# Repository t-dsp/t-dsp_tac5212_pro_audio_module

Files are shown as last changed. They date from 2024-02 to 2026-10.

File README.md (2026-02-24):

# T-DSP TAC5212 Pro Audio Module

**Part of the [T-DSP](https://t-dsp.com) open modular audio platform.**

A compact (50mm x 34.5mm) stereo audio codec module built around the **Texas Instruments TAC5212** high-performance audio codec.

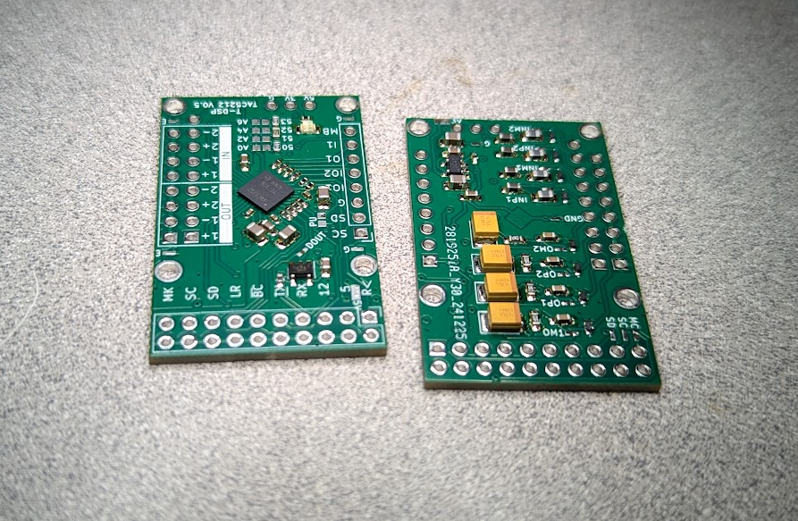
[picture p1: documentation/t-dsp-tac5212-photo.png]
T-DSP TAC5212 Pro Audio Module


T-DSP TAC5212 Pro Audio Module - Top Isometric

| | |
|:---:|:---:|
| Top | Bottom |
| Front | Rear |

**[View 3D Render Gallery](https://t-dsp.github.io/t-dsp_tac5212_pro_audio_module/gallery.html)** -- interactive slideshow of all board views

## About T-DSP

T-DSP is an open modular audio platform designed for musicians, engineers, and developers who want powerful digital signal processing in a flexible, hackable format. Built around the [Teensy](https://www.pjrc.com/teensy/) microcontroller and the [Teensy Audio Library](https://www.pjrc.com/teensy/td_libs_Audio.html), T-DSP combines studio-quality audio with a growing library of open-source modules for mixing, synthesis, effects, and more.

Whether you're building a custom digital mixer, crafting a unique instrument, or prototyping audio products, T-DSP gives you the tools to bring your ideas to life.

Join the community, contribute to the library, or grab a module and start patching. Learn more at [t-dsp.com](https://t-dsp.com).

## Overview

This codec module provides stereo ADC and DAC conversion and is one of the core building blocks of the T-DSP platform. It is designed as a **chip-on-board module** -- a complete, self-contained audio codec that solders directly onto a user-designed backplane PCB, just like any other component. A KiCad footprint is provided so you can drop the module into your own backplane design, add whatever jacks and connectors your application needs, and build a custom audio device without dealing with codec layout or analog design.

## Audio Capabilities

### Inputs (2 differential pairs)
- Line-level (consumer -10dBV or professional +4dBu)
- Instrument-level (guitar/bass) with external preamp/buffer (preamp and buffer modules are on the T-DSP project roadmap)
- Microphone (dynamic, with up to 12dB analog channel gain and additional digital gain)
- Programmable input impedance (5k/10k/40k ohm), DC-coupled. Optional 100k ohm bias resistors on board.
- 2 VRMS full-scale differential input

### Outputs (2 differential pairs)
- Headphone drive (16-300 ohm, 62.5mW @ 16 ohm, ~31mW @ 32 ohm)
- Consumer line out (-10dBV)
- Professional balanced output (+4dBu)
- 10 ohm output impedance, 2 VRMS differential output

## Digital Interface

- **I2S/PCM** audio data (DIN, DOUT, BCLK, LRCK, MCLK)
- **I2C** control bus for codec register configuration
- **GPIO** pins for additional control and sensing

The T-DSP platform is developed with [Teensy](https://www.pjrc.com/teensy/) and the [Teensy Audio Library](https://www.pjrc.com/teensy/td_libs_Audio.html), but the module uses standard I2S and I2C interfaces and can work with any compatible microcontroller or DSP platform.

## Modular Architecture

The module connects to your backplane via **2.54mm (0.1") header pins** (52 pins total), organized into functional groups. Headers can be male/female for a removable connection, or soldered permanently with straight pins:

- **DSP IO** (20 pins) -- digital audio (I2S), I2C control, MCLK, and power. Also available as a 20-pin ribbon header for off-board connection via standard ribbon cable.
- **Analog IO** (16 pins) -- stereo input and output pairs with analog ground references.
- **GPIO** (8 pins) -- additional I2C, general-purpose IO, and digital ground.
- **Power** (8 pins) -- 5V, 3.3V, MIC_BIAS, and ground lines.

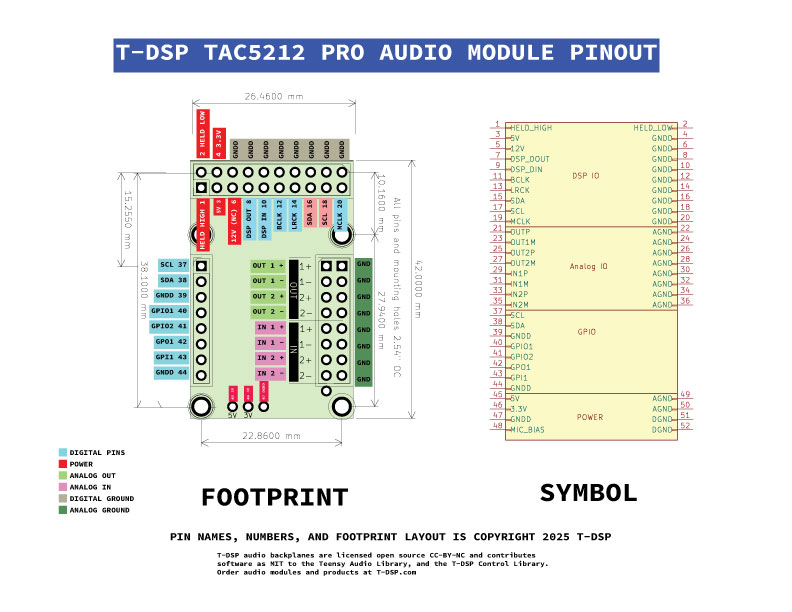
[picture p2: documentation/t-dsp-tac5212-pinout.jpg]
T-DSP TAC5212 Pro Audio Module Pinout


### Backplane Integration

A KiCad footprint for the module is included in `/lib_fp/`, allowing you to import it directly into your own backplane PCB design. You handle the jacks, connectors, and mechanical layout on your backplane -- the module takes care of codec, filtering, and power regulation.

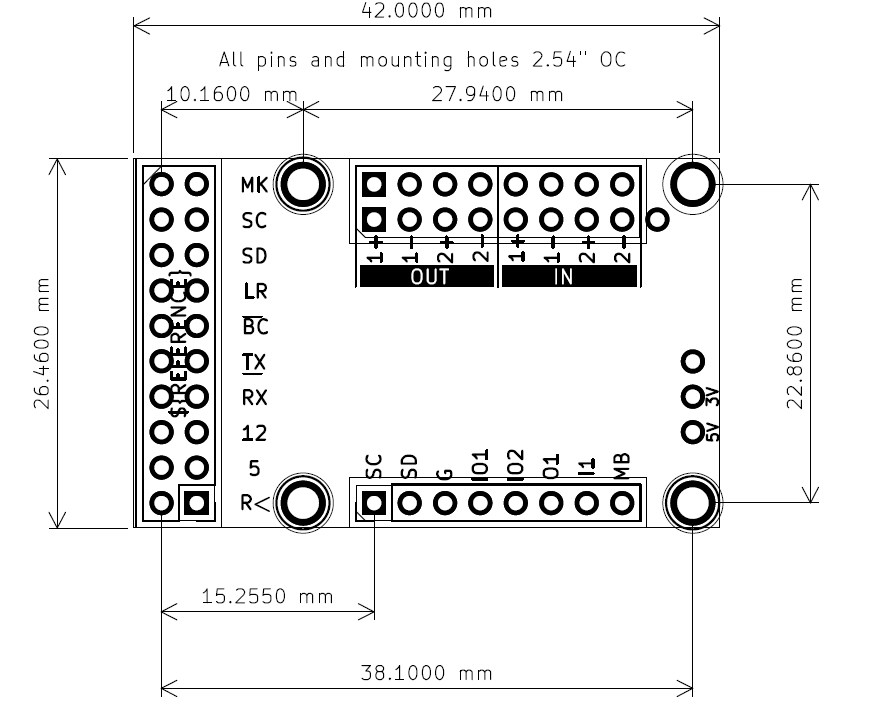
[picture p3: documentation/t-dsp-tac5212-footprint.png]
T-DSP TAC5212 Pro Audio Module Footprint


**Example backplanes built with the T-DSP module:**

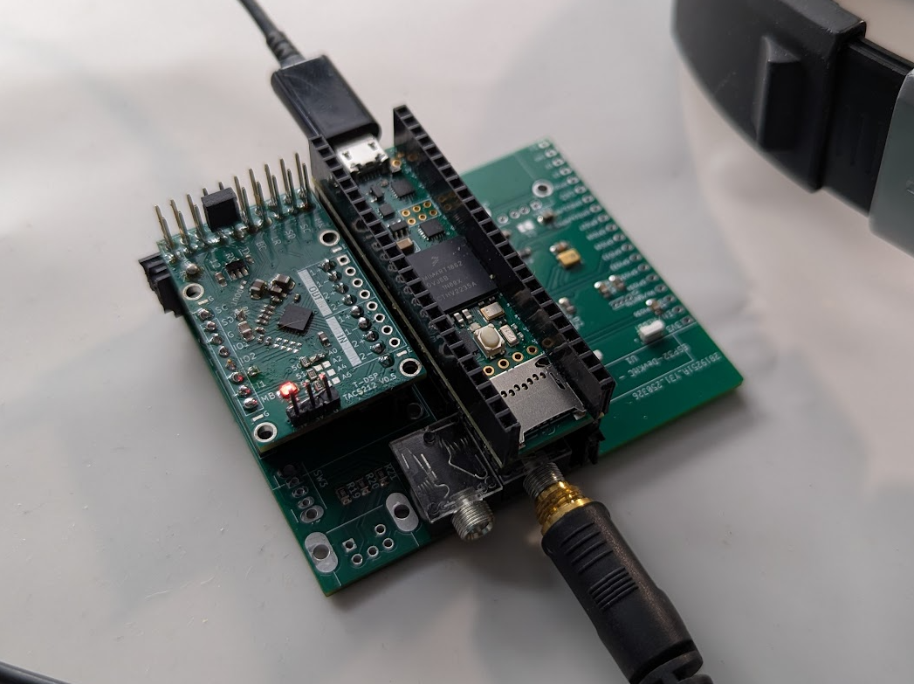
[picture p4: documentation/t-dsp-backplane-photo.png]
Backplane example - prototype


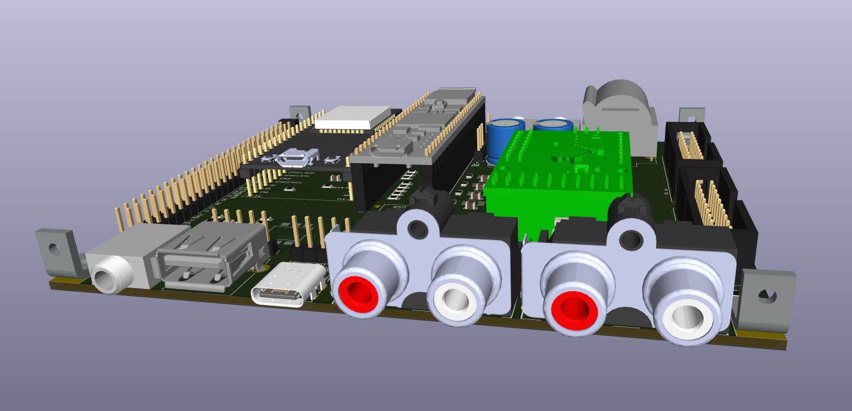
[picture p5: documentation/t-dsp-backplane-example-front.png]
Backplane example - 3D front

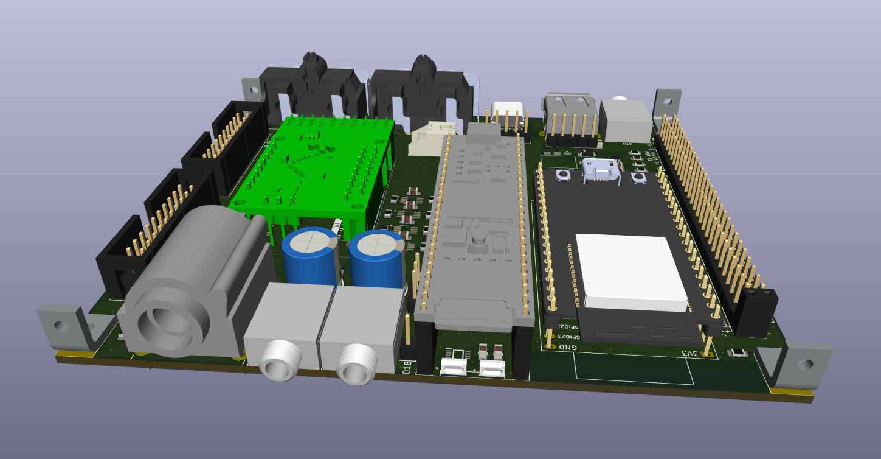
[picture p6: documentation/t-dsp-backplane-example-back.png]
Backplane example - 3D back


### Multi-Module Chaining

Because the digital outputs are buffered on each module, multiple modules can run together on the same digital bus. You can daisy-chain modules in two ways:

- **On the backplane** -- route the digital bus as board traces between multiple module footprints.
- **Via ribbon cable** -- use a ribbon cable with multiple taps to connect up to 4 modules per chain.

System designers only need to focus on analog signal routing. The buffered digital bus works reliably over longer distances and across many modules.

## On-Board Circuitry

- LDO regulator for clean 3.3V analog power
- Buffered digital outputs for reliable backplane distribution
- TVS protection on audio outputs
- Ferrite bead RF filtering on audio inputs
- Solder jumpers for I2C address configuration
- Power indicator LED

The T-DSP platform has gone through several design iterations. The bench prototype below is from an earlier version of the project -- a different module architecture that helped shape the current design.

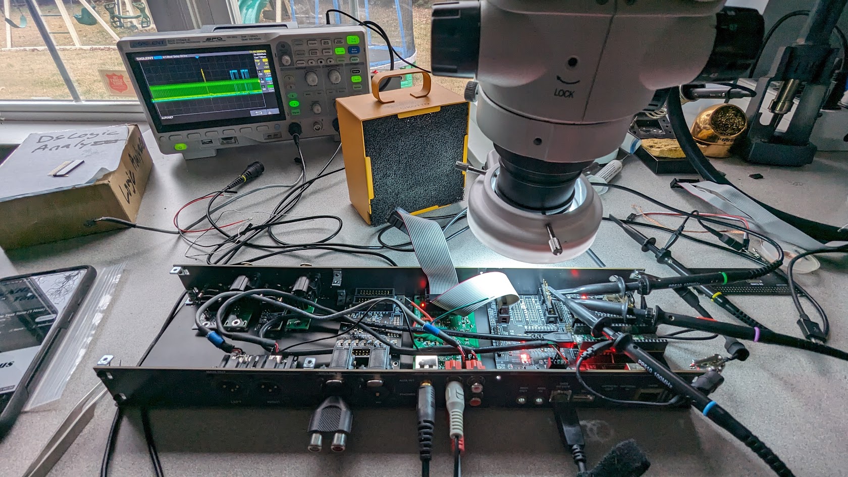
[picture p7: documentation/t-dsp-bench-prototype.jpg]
Earlier T-DSP prototype on the bench


## Project Files

| Directory | Contents |
|---|---|
| `/3d_models/` | 3D models for PCB components and enclosure |
| `/documentation/` | TAC5212 datasheets, [schematic PDF](documentation/t-dsp-tac5212-schematic.pdf), [footprint drawing](documentation/t-dsp-tac5212-footprint.pdf), and [3D model (STL)](documentation/t-dsp_tac5212_pro_audio_module.stl). View online: [schematic](https://kicanvas.org/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) and [PCB layout](https://kicanvas.org/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) via KiCanvas |
| `/lib_fp/` | Custom KiCad footprint libraries |
| `/lib_sch/` | Custom KiCad schematic symbol libraries |
| `/pages/` | [3D Render Gallery](https://t-dsp.github.io/t-dsp_tac5212_pro_audio_module/gallery.html), [Interactive BOM](https://t-dsp.github.io/t-dsp_tac5212_pro_audio_module/ibom.html) |
| `/scripts/` | LCSC enrichment and BOM verification scripts |

## Building Manufacturing Files

Manufacturing files (gerbers, drill, BOMs, CPL, interactive BOM) are generated automatically by [KiBot](https://github.com/INTI-CMNB/KiBot) via GitHub Actions on every push to `main`. Download the ZIP from the **Actions** tab or from **Releases**.

The ZIP includes:
- Gerbers and drill files for any PCB fabricator
- JLCPCB BOM (`*_bom_JLCPCB.csv`) with LCSC part numbers
- Generic BOM (`*_bom_generic.csv`) with manufacturer part numbers
- Pick and place / CPL file
- Schematic PDF and PCB layout PDF
- Interactive BOM (also deployed live: [view iBOM](https://t-dsp.github.io/t-dsp_tac5212_pro_audio_module/ibom.html))

To build locally, install [Docker](https://www.docker.com/) and run:

```powershell
docker run --rm -v "${PWD}:/workspace" -w /workspace ghcr.io/inti-cmnb/kicad9_auto:latest kibot -c .kibot.yaml -b t-dsp_tac5212_pro_audio_module.kicad_pcb -e t-dsp_tac5212_pro_audio_module.kicad_sch -d manufacturing
```

Output files appear in `manufacturing/t-dsp_tac5212_pro_audio_module/`.

## Related Projects

Browse all T-DSP modules and backplanes on the [T-DSP GitHub organization](https://github.com/orgs/t-dsp/repositories).

## Status

This revision has not yet been built. The previous board was functional but had a few signal routing errors and needed a redesign of the analog output stage for low-impedance headphone drive. Those issues have been addressed in the current design.

If you build one, we'd love to hear how it goes -- please open an issue or reach out with your findings.

## Contact

For consulting, custom backplane design, or commercial licensing inquiries, reach out via [LinkedIn](https://linkedin.com/in/jayshoe).

## License

This project is licensed under the [Creative Commons Attribution-NonCommercial-ShareAlike 4.0 International (CC BY-NC-SA 4.0)](https://creativecommons.org/licenses/by-nc-sa/4.0/).

You are free to share and adapt this work for non-commercial purposes, as long as you give appropriate credit and distribute any derivatives under the same license.

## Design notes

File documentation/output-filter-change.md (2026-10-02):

# DAC output filter change (next respin / rework of built units)

**Date:** 2026-10-02
**Status:** Decided, not yet applied to the schematic. BOM change only, no layout change.

## Symptom

Harsh, fatiguing top end from the DAC outputs. Present on headphones, much worse through a
power amplifier and speakers. The module is wired straight to the amplifier; the backplanes
(`t-dsp_XLR_2x2`, `t-dsp_RCA_8x8`) only add a coupling capacitor before the jack, so nothing
between the codec and the amplifier filters the DAC's out-of-band noise.

## Cause

The output network on every DAC leg is 10 R in series and 4.7 nF to AGND. Its corner is about
3.4 MHz, so the delta-sigma noise from a few hundred kHz upward reaches the cable and the
amplifier input unattenuated. Some amplifier input stages fold that back into the audio band.

## Current network (identical on all four legs)

| Position | OUT1P / OUT1M / OUT2P / OUT2M | Value | Fitted |
|---|---|---|---|
| Series | R108 / R111 / R132 / R135 | 10 R, 0603 | yes |
| Parallel to series R | R127 / R128 / R129 / R130 | 0603, "DNP" | no |
| Shunt to AGND | C113 / C114 / C120 / C122 | 4.7 nF, 0603 | yes |
| Coupling link | R161 / R162 / R163 / R134 | 0 R, 0603 | yes |
| Coupling cap (alternative to the link) | C110 / C117 / C121 / C123 | 47 uF, EIA-3528 | no |
| ESD at the connector | D108 / D109 / D110 / D111 | TPD1E10B06, 0402 | yes |

Connector: board_outline108 pins 21 (OUT1P+), 23 (OUT1M+), 25 (OUT2P+), 27 (OUT2M+), AGND on
22 / 24 / 26 / 28. "Earth" is the analog ground net.

## The change

| References | Now | Change to | Part | LCSC |
|---|---|---|---|---|
| R108, R111, R132, R135 | 10 R | **220 R** 1 %, 0603 | Uniroyal 0603WAF2200T5E | C22962 (Basic) |
| C113, C114, C120, C122 | 4.7 nF | **10 nF C0G 50 V**, 0603 | Murata GRM1885C1H103JA01D | C85973 |

Everything else stays as it is: 0 R links fitted, 47 uF caps not fitted, R127-R130 not fitted,
ESD diodes unchanged.

Result: first-order corner at 72 kHz. -0.3 dB at 20 kHz, -9 dB at 200 kHz, -23 dB at 1 MHz,
-32 dB at 3 MHz. 220 R into a 47 k amplifier input loses 0.04 dB; into 10 k, 0.19 dB.

Why 220 R / 10 nF rather than 100 R / 22 nF: same corner, and the 10 nF C0G is a stocked
Murata part with a verified LCSC listing. Use C0G/NP0 (not X7R) and matched parts: X7R adds
voltage-dependent distortion, and a P/M mismatch converts common-mode noise to signal on a
balanced input.

## Before ordering: bench test on a current unit

1. Solder a 100 nF film cap across an RCA jack (tip to sleeve) on the RCA backplane, or 47 nF
   across XLR pins 2 and 3 on the XLR backplane. With the module's 10 R this makes a corner near
   160 kHz.
2. If the harshness disappears, the BOM change above is the production fix.
3. Remove the test cap once the module is changed. A large cap at the jack together with the
   220 R would start eating the top octave (100 nF with 220 R is a 7 kHz corner).

## Backplane notes (no change required for this fix)

- XLR 2x2: 470 uF electrolytic per leg to XLR pins 2 and 3. Polar: positive end toward the
  module (the codec pin sits at about 1.5 V DC). Not phantom-safe: 48 V phantom on a mixer input
  charges those caps the wrong way and reaches the module. Add 100 R per leg and a clamp before
  that board goes to anyone else.
- RCA 8x8: Nichicon UEP 10 uF bipolar on the P leg, M leg open. Fine as is.
- Optional second pole at the jack on a future backplane spin: 100 R in series and 2.2 nF to
  AGND right at the jack (XLR: 2.2 nF across pins 2 and 3 plus 1 nF from each leg to pin 1).
  Only needed if a trace of edge remains after the module change.

## Single-ended and balanced use

The same build serves both. Balanced: take P and M. Single-ended: take P and AGND, leave M
open. If a build is to be DC-blocked on the module instead of on the backplane, fit the 47 uF
on the EIA-3528 pads (B-case polymer tantalum, 47 uF 6.3 V, positive end toward the codec) and
remove the corresponding 0 R link.

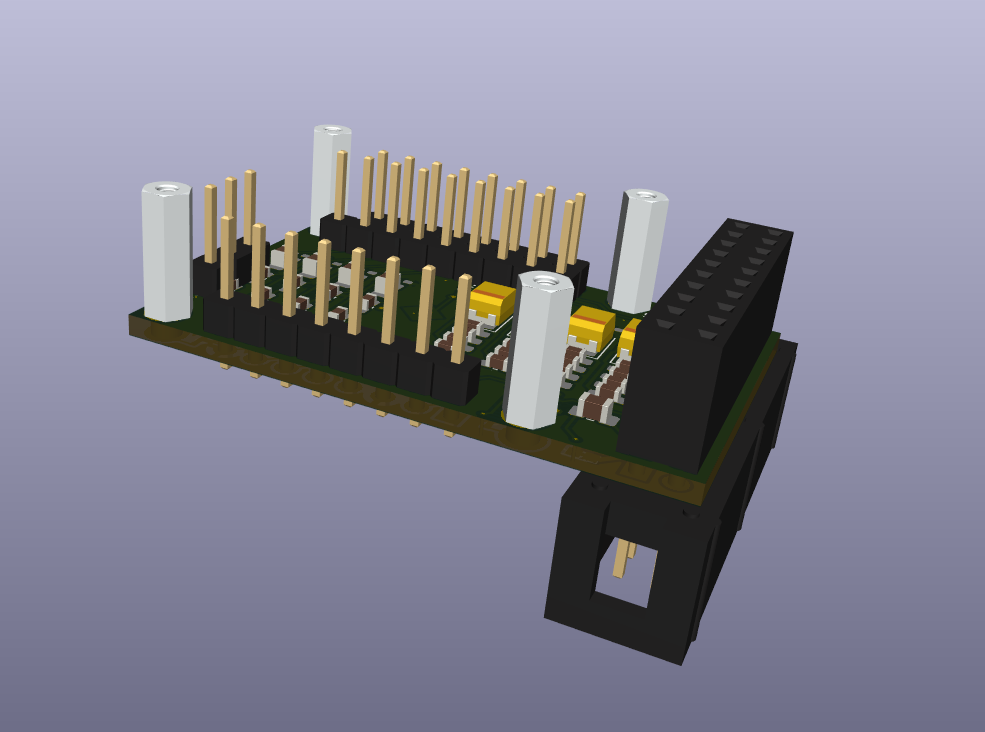
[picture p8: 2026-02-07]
documentation/t-dsp-tac5212-3d-bottom.png

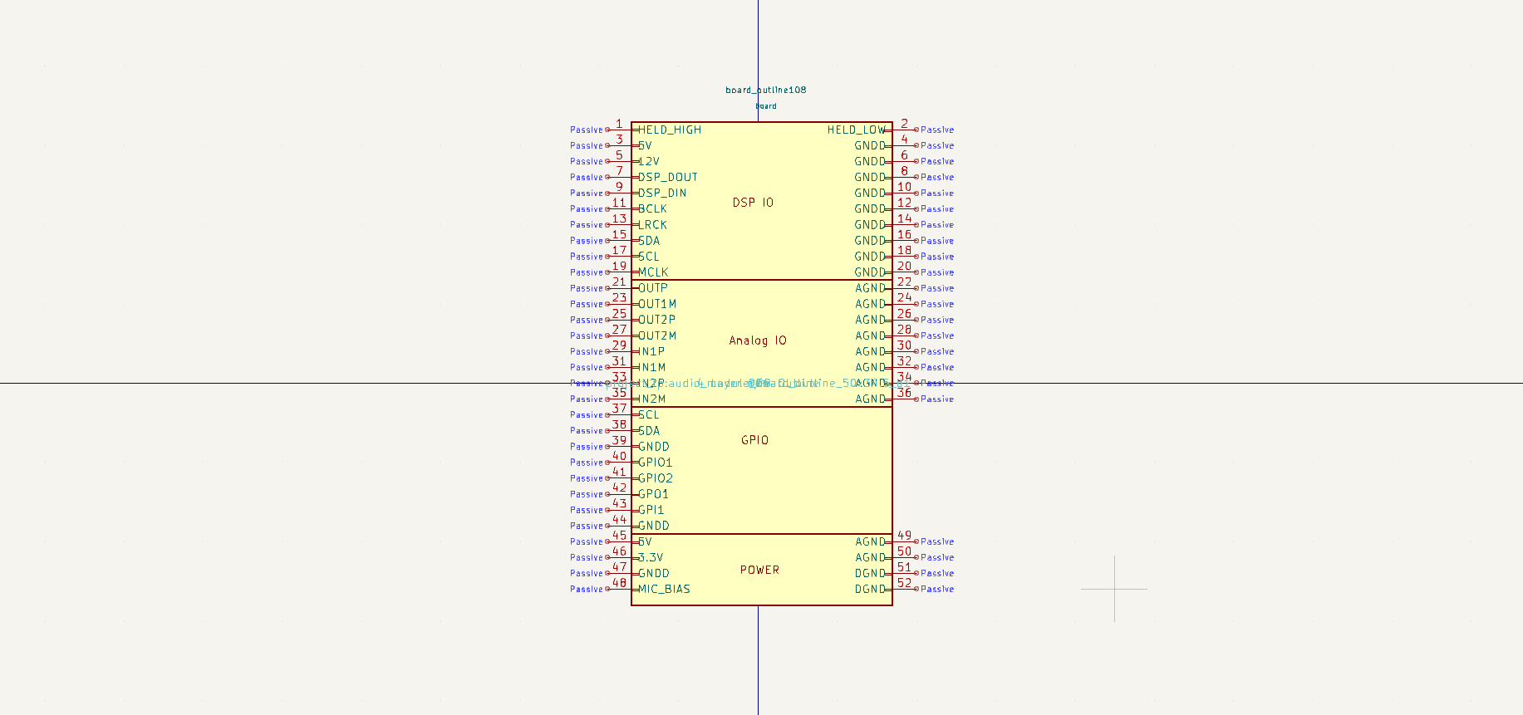
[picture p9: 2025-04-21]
documentation/t-dsp-tac5212-symbol.png

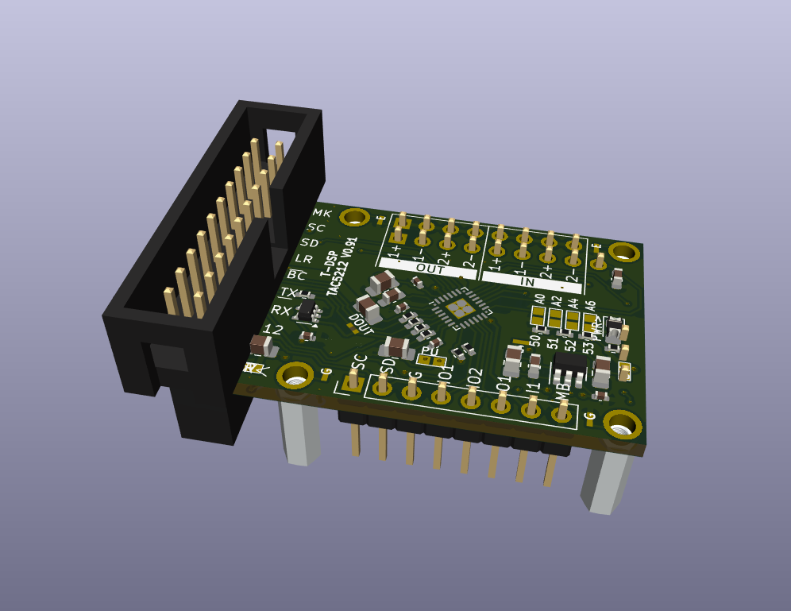
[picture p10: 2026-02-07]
documentation/t-dsp-tac5212-3d-top.png

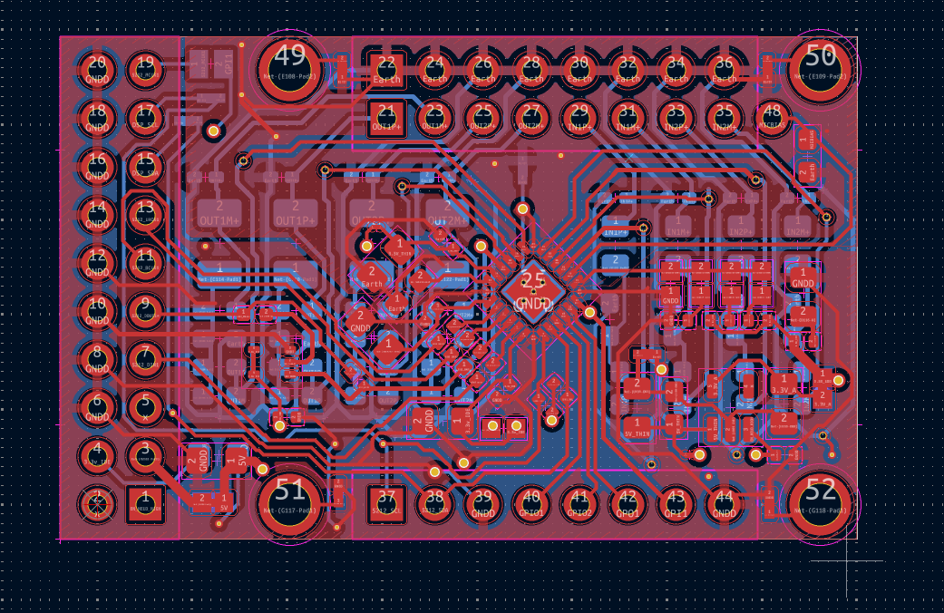
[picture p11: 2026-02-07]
documentation/t-dsp-tac5212-pcb-layout.png

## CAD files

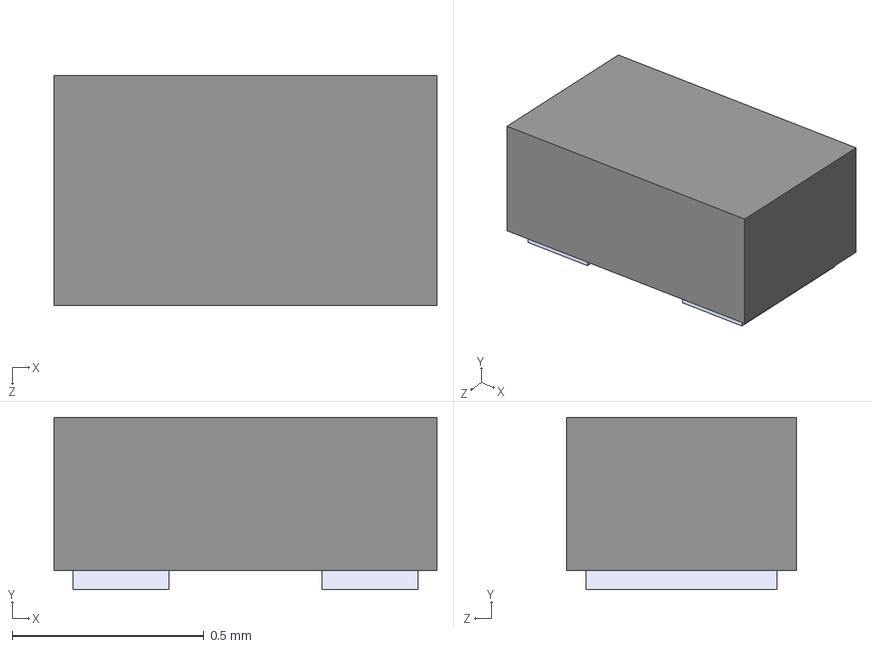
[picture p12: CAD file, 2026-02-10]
3d_models/TPD1E10B06DPYR.STEP
1.00 x 0.45 x 0.6 mm

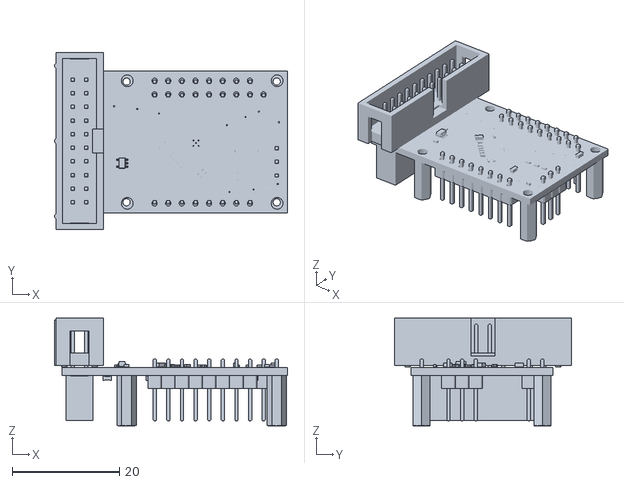
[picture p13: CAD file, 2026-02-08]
documentation/t-dsp_tac5212_pro_audio_module.stl
43.4 x 33.1 x 20.0

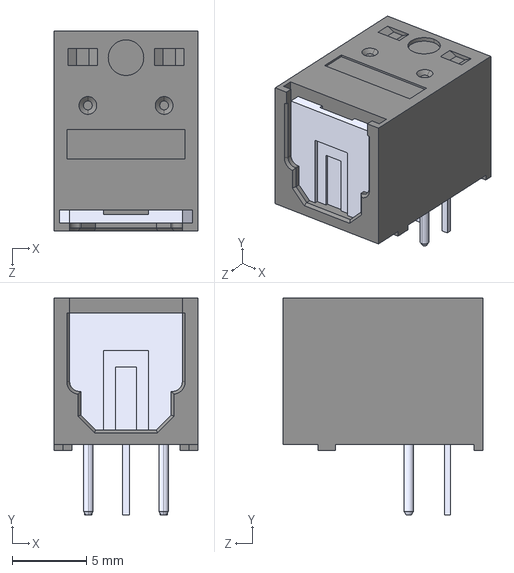
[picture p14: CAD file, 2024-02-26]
lib_sch/PLT133_T10W/PLT133_T10W.step
9.70 x 14.7 x 13.5 mm

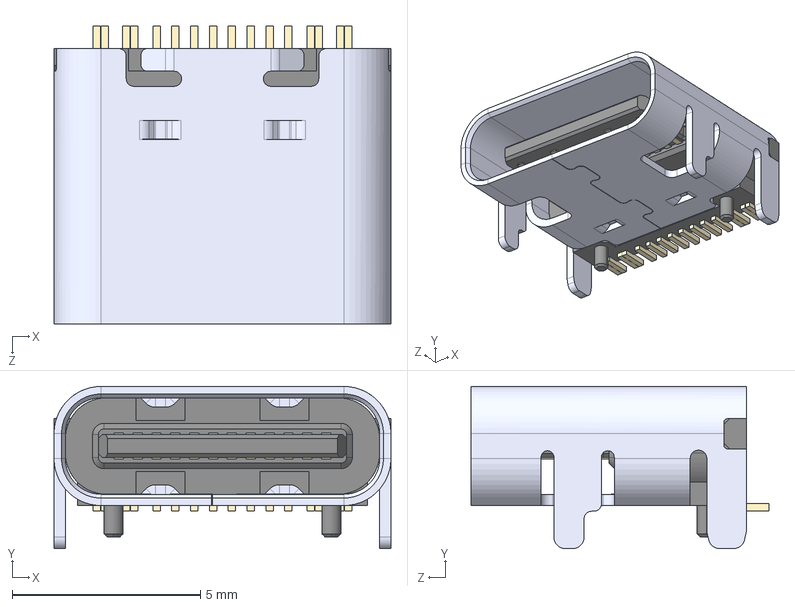
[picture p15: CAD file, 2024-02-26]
lib_sch/TYPE-C-31-M-12/TYPE-C-31-M-12.step
8.94 x 4.30 x 7.90 mm

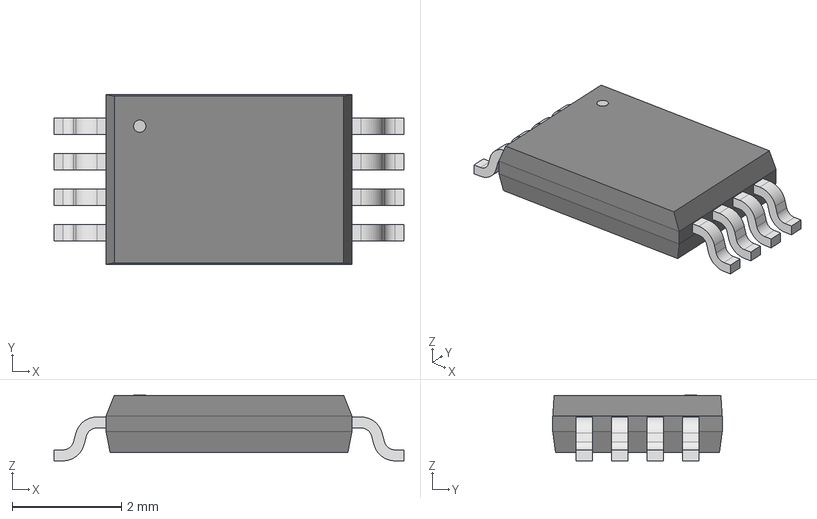
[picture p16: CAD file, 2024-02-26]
lib_sch/ul_23LC1024IST/2020-04-10_17-26-26/STEP/TSSOP8_MC.step
6.40 x 3.10 x 1.20 mm

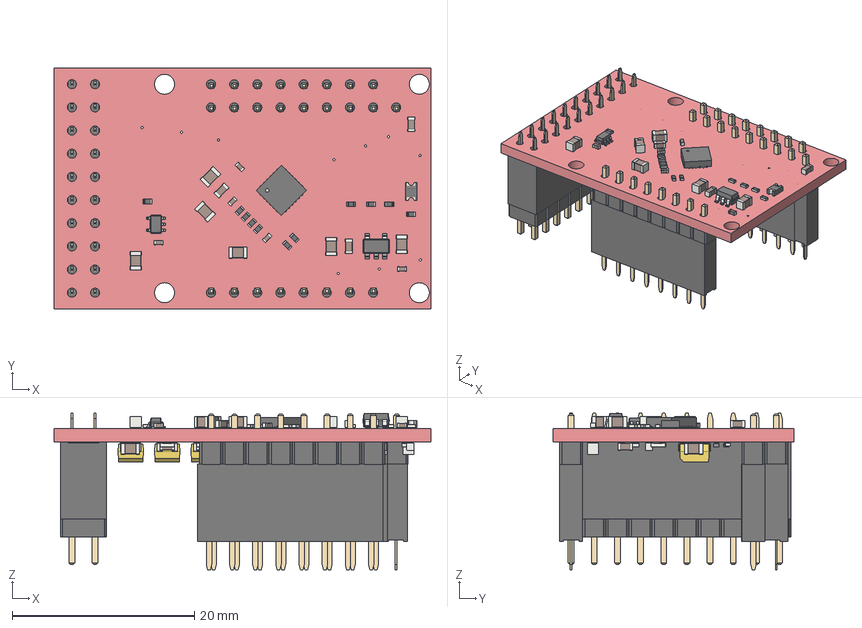
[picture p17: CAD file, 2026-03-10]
t-dsp_tac5212_pro_audio_module_pcb_mount.step
41.3 x 26.5 x 17.2 mm
R_0402_1005Metric x 15
PinHeader_1x08_P2.54mm_Vertical x 2
PinHeader_1x09_P2.54mm_Vertical
PinSocket_2x10_P2.54mm_Vertical
PinSocket_2x08_P2.54mm_Vertical
PinSocket_1x08_P2.54mm_Vertical
PinSocket_1x01_P2.54mm_Vertical
PinHeader_2x10_P2.54mm_Vertical
C_0805_2012Metric x 11
C_0402_1005Metric x 5
C_0603_1608Metric x 11
SOT-353_SC-70-5
SOT-23-5
D_0805_2012Metric
VQFN-24-1EP_4x4mm_P0.5mm_EP2.45x2.45mm
R_0603_1608Metric x 16
CP_EIA-3528-21_Kemet-B x 4
TPD1E10B06DPYR x 8
t-dsp_tac5212_pro_audio_module_PCB

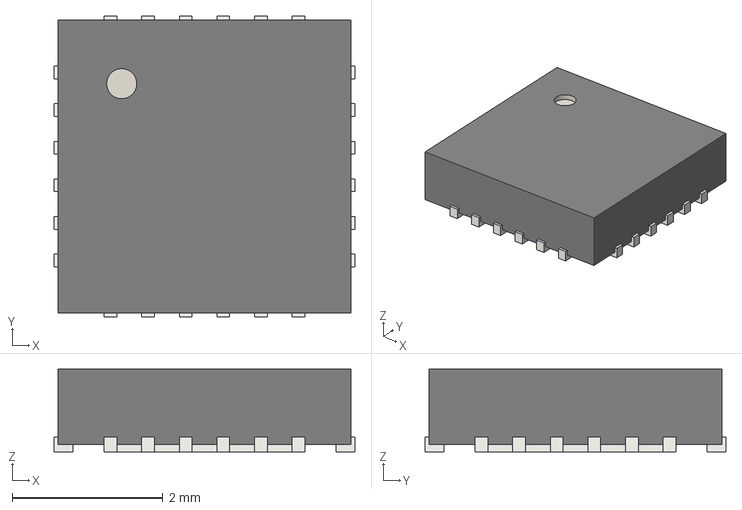
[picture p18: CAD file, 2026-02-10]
3d_models/VQFN-24-1EP_4x4mm_P0.5mm_EP2.45x2.45mm.step
4.00 x 4.00 x 1.10 mm

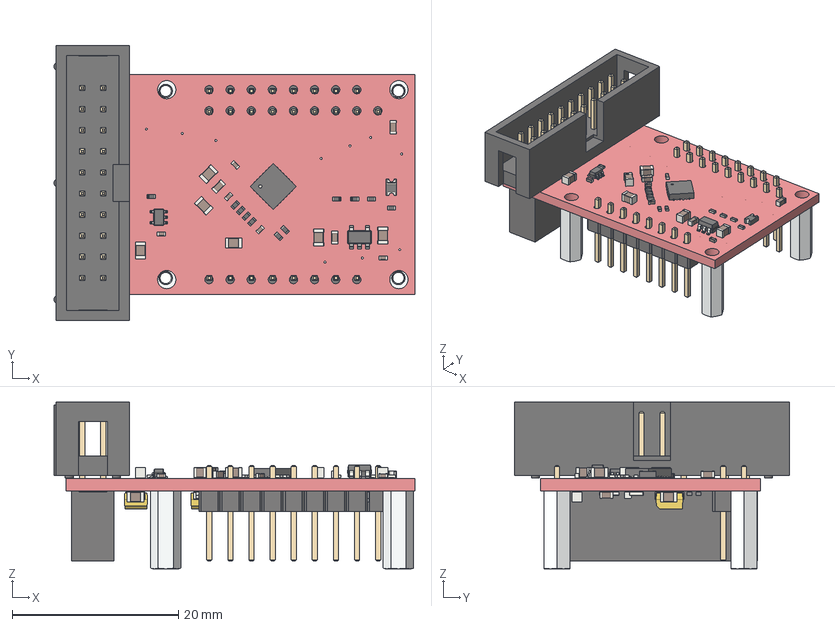
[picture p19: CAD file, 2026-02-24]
t-dsp_tac5212_pro_audio_module.step
43.4 x 33.1 x 20.0 mm
R_0402_1005Metric x 11
IDC-Header_2x10_P2.54mm_Vertical
1808--3DModel-STEP-630548 x 4
PinHeader_1x08_P2.54mm_Vertical x 2
PinHeader_1x09_P2.54mm_Vertical
PinSocket_2x10_P2.54mm_Vertical
C_0805_2012Metric x 11
C_0402_1005Metric x 5
C_0603_1608Metric x 11
SOT-353_SC-70-5
SOT-23-5
D_0805_2012Metric
VQFN-24-1EP_4x4mm_P0.5mm_EP2.45x2.45mm
R_0603_1608Metric x 16
CP_EIA-3528-21_Kemet-B x 4
TPD1E10B06DPYR x 8
t-dsp_tac5212_pro_audio_module_PCB

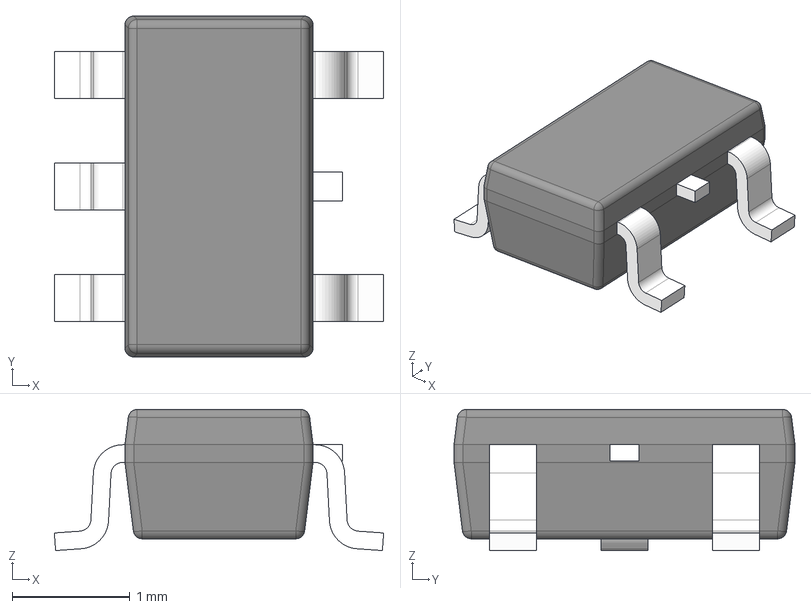
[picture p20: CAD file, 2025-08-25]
3d_models/SN74LVC1G66DBVR.stp
2.80 x 2.90 x 1.20 mm
BODY-SOT
LEAD-SOT x 5
LEAD-DUMMY

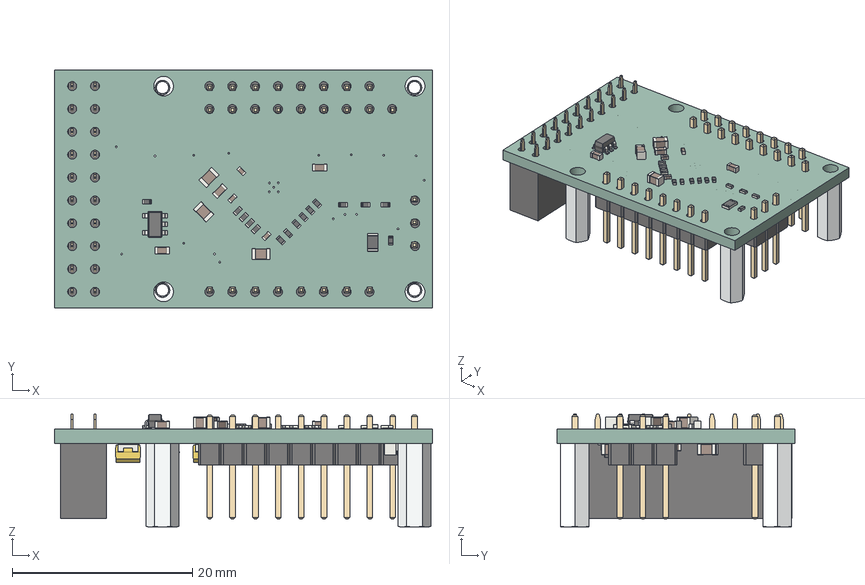
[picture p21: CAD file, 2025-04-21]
tlv320aic3105_audio_board50.step
42.0 x 26.5 x 12.5 mm
R_0402_1005Metric x 16
PinHeader_1x08_P254mm_Vertical x 2
PinHeader_1x09_P254mm_Vertical
PinSocket_2x10_P2.54mm_Vertical
PinHeader_1x03_P254mm_Vertical
C_0805_2012Metric x 9
C_0402_1005Metric x 3
SOT_23_5 x 2
C_0603_1608Metric x 13
R_0805_2012Metric
R_0603_1608Metric x 4
CP_EIA_3528_21_Kemet_B x 4
_autosave-tac5212_audio_board_single_ended_PCB

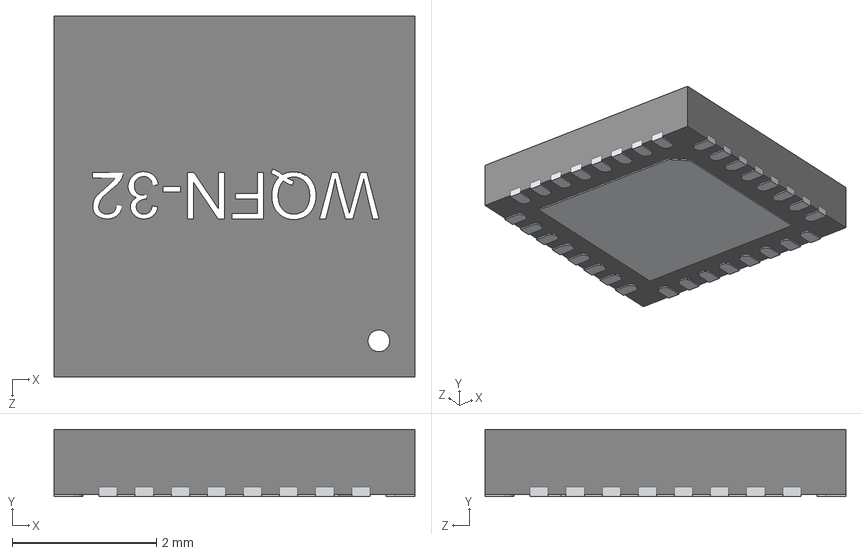
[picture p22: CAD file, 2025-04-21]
3d_models/WQFN-32.step
5.00 x 0.93 x 5.00 mm

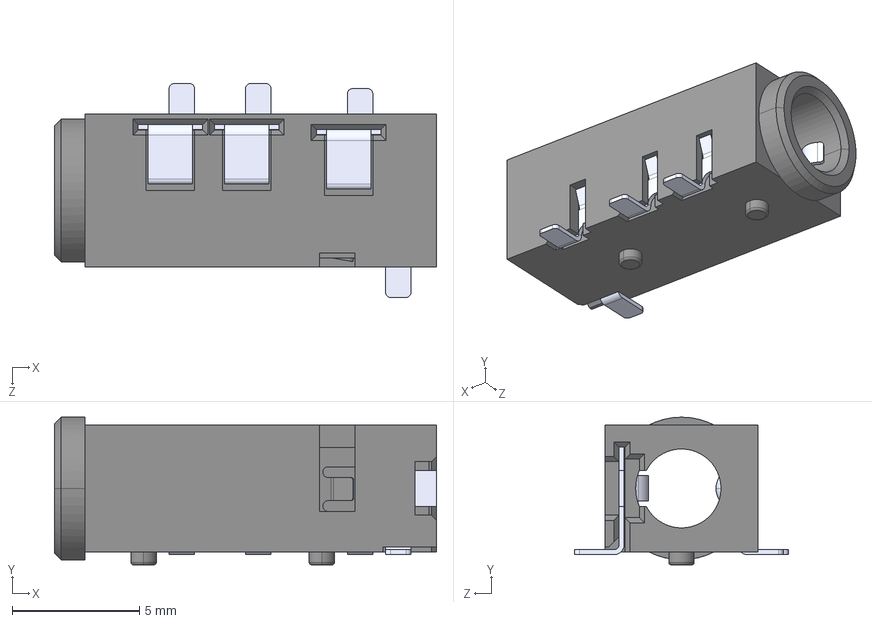
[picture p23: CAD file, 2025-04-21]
3d_models/SJ2-3574A-SMT-TR.step
15.0 x 5.80 x 8.40 mm

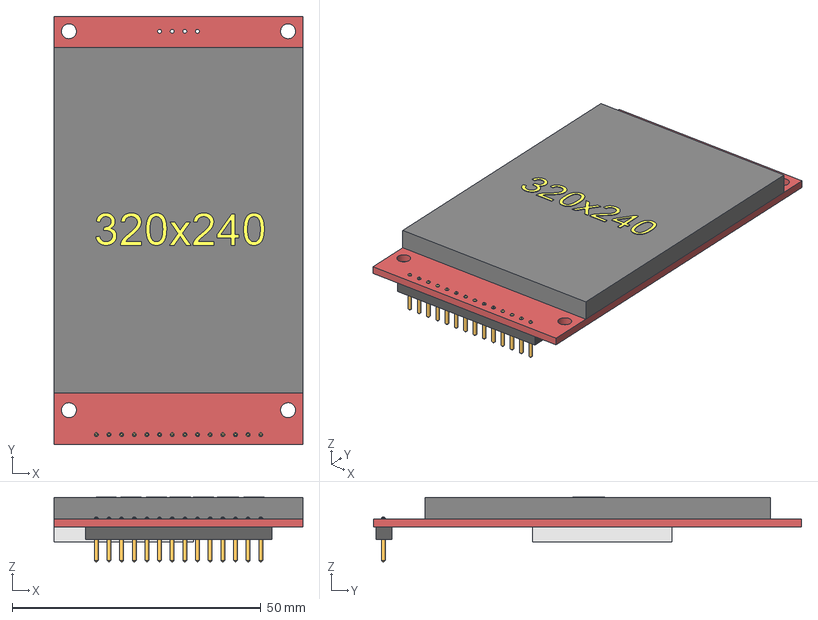
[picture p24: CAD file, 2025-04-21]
3d_models/TFT_320x240_touch_r0.step
50.0 x 86.0 x 13.1 mm
Body-header
Body-pins
Body-display
Body-sdcard
Body-board

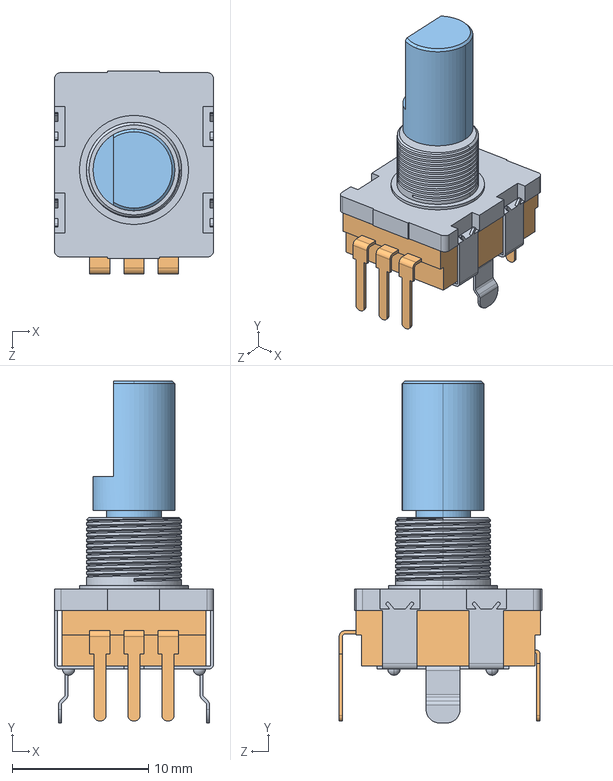
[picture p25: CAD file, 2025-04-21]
3d_models/EN11-HSM1AF15.STEP
11.7 x 25.1 x 14.9 mm

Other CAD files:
lib_sch/ul_23LC1024IST/2020-04-10_17-26-26/STEP/TSSOP8_MC-M.step
lib_sch/ul_23LC1024IST/2020-04-10_17-26-26/STEP/TSSOP8_MC-L.step
3d_models/SK6812.step
3d_models/1808--3DModel-STEP-630548.STEP
3d_models/2120--3DModel-STEP-630548.STEP
3d_models/3-D NC3MAH.stp
3d_models/3-D NCJ6FAH.stp
3d_models/3-D NCJ6FI-H-0.stp
3d_models/3-d-nmj6hcd3.stp
3d_models/3.5MM_STEREO_35RAPC4BHN2.STEP
3d_models/35RAPC3BH3.STEP
3d_models/35RAPC7JS.STEP
3d_models/35RAPC7JS_SIMPLIFIED.step
3d_models/3_2SPI-TFT-Modul_ILI9341.STEP
3d_models/4691.step
3d_models/74LS00.step
3d_models/Bracket 4-40 621.STEP
3d_models/COMBO-NCJ6FA-H.step
3d_models/COMBO_XLR_NCJ6FI-H-0.stp
3d_models/DC_BARREL_PJ-202AH.step
3d_models/DIN-5.STEP
3d_models/FCR6842032R ORJ3.stp
3d_models/FCR6842032T OTJ3.stp
3d_models/J1B1211CCD.STEP
3d_models/JST - XH - Thru (V) - 2Pin - 2.54mm.stp
3d_models/LED_SK6812MINI-E.step
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

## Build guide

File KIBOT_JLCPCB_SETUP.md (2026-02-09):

# KiBot JLCPCB Setup Notes

Reference for generating JLCPCB-ready manufacturing files from KiCad using KiBot + Docker.

## Prerequisites

- **Docker**: Required (kicad-cli and KiBot are NOT installed locally)
- **Docker image**: `ghcr.io/inti-cmnb/kicad9_auto:latest` (bundles KiBot + KiCad 9)
- Pull it first: `docker pull ghcr.io/inti-cmnb/kicad9_auto:latest`

## Project Files

```
t-dsp_tac5212_pro_audio_module.kicad_pro
t-dsp_tac5212_pro_audio_module.kicad_pcb   (4-layer: F.Cu, In1.Cu, In2.Cu, B.Cu)
t-dsp_tac5212_pro_audio_module.kicad_sch   (LCSC field with 237 occurrences)
```

## Run Command

PowerShell:
```powershell
docker run --rm -v "${PWD}:/workspace" -w /workspace ghcr.io/inti-cmnb/kicad9_auto:latest kibot -c .kibot.yaml -b t-dsp_tac5212_pro_audio_module.kicad_pcb -e t-dsp_tac5212_pro_audio_module.kicad_sch
```

cmd.exe:
```cmd
docker run --rm -v "%cd%:/workspace" -w /workspace ghcr.io/inti-cmnb/kicad9_auto:latest kibot -c .kibot.yaml -b t-dsp_tac5212_pro_audio_module.kicad_pcb -e t-dsp_tac5212_pro_audio_module.kicad_sch
```

Git Bash (must disable MSYS path conversion):
```bash
MSYS_NO_PATHCONV=1 docker run --rm -v "${PWD}:/workspace" -w /workspace ghcr.io/inti-cmnb/kicad9_auto:latest kibot -c .kibot.yaml -b t-dsp_tac5212_pro_audio_module.kicad_pcb -e t-dsp_tac5212_pro_audio_module.kicad_sch
```

## Output

All files go to `JLCPCB/` directory:
- Gerber files (.gtl, .gbl, .g1, .g2, .gto, .gbo, .gts, .gbs, .gtp, .gbp, .gm1)
- Drill files (-PTH.drl, -NPTH.drl, drill maps)
- BOM CSV: columns = Comment, Designator, Footprint, LCSC Part #
- CPL CSV: columns = Designator, Val, Package, Mid X, Mid Y, Rotation, Layer
- ZIP containing everything above

## Issues to Fix Before Running

### 1. Malformed Reference Designators (BLOCKING)

KiBot will ERROR and skip BOM/CPL generation if any reference designator starts with a digit.

Two components have this problem:
- **`5V108`** — Device:NetTie_2, value "jumper", footprint project_fp:jumper_slice_1mm, DNP, at (57.15, 226.06) in schematic
- **`3V108`** — Device:NetTie_2, value "jumper", footprint project_fp:jumper_slice_1mm, DNP, at (116.84, 355.6) in schematic

**Fix in KiCad**: Rename these to valid designators (e.g. NT110, NT111 or JP110, JP111). KiCad will automatically update the associated net names. Do this in KiCad's schematic editor (not by text editing) so it handles all the cross-references properly.

Note: NT108 and NT109 already exist in the schematic (different net ties with footprint NetTie-2_SMD_Pad0.2mm), so don't use those numbers.

Gerbers generate fine from the PCB file regardless — only BOM/CPL are blocked.

### 2. Non-Blocking Warnings (cosmetic, won't prevent output)

**Trailing spaces in TAC5212EVM fields (W037):**
- D116: `LTST-C170KRKT ` (trailing space)
- R115, R118, R119: `ERJ-2GE0R00X ` (trailing space)
- Fix: Edit these fields in KiCad symbol properties, remove trailing space

**Missing library components (W043):**
- `proejct_lib:Jumper_NO_Small-Device_1` and `_2`
- Note the typo: "proejct" not "project"
- The whole project uses `proejct_lib` throughout — this is a legacy typo baked into the project

**Malformed component values (W020/W127):**
- C113, C114, C120, C122: `0.0047µF (4.7nF)` — KiBot can't parse this format. Consider `4.7nF`
- C124: `10UF confirm polarity` — extra text. Consider `10uF`
- R120: `2.21k ohm` — redundant "ohm". Consider `2.21k`

**BOM field conflicts (W004):**
These happen when KiBot groups components with same Value but different metadata. Not output-breaking but may indicate real BOM issues:
- C109,C112,C116 (0402) grouped with C128,C129 (0603) — same value "0.1uF" but different packages
- C124-C127: package mismatch C0805 vs C0603
- R120,R121,R126: different LCSC codes (C138019 vs C60491) — R126 may be a different value (100K vs 2.21k)

## .kibot.yaml Configuration

Place this file at the repo root as `.kibot.yaml`:

```yaml
# KiBot configuration for JLCPCB manufacturing outputs
# Project: T-DSP TAC5212 Pro Audio Module
# Board: 4-layer (F.Cu, In1.Cu, In2.Cu, B.Cu)

kibot:
  version: 1

filters:
  - name: only_jlc_parts
    comment: 'Only parts with LCSC code'
    type: generic
    include_only:
      - column: 'LCSC'
        regex: '^C\d+'

variants:
  - name: rotated
    comment: 'JLCPCB rotation correction'
    type: kibom
    variant: rotated
    pre_transform: _rot_footprint_jlcpcb

outputs:
  - name: JLCPCB_gerbers
    comment: Gerbers compatible with JLCPCB
    type: gerber
    dir: JLCPCB
    options:
      exclude_edge_layer: true
      exclude_pads_from_silkscreen: true
      plot_sheet_reference: false
      plot_footprint_refs: true
      plot_footprint_values: false
      force_plot_invisible_refs_vals: false
      tent_vias: true
      use_protel_extensions: true
      create_gerber_job_file: false
      disable_aperture_macros: true
      gerber_precision: 4.6
      use_gerber_x2_attributes: false
      use_gerber_net_attributes: false
      line_width: 0.1
      subtract_mask_from_silk: true
      inner_extension_pattern: '.g%n'
    layers:
      - F.Cu
      - B.Cu
      - In1.Cu
      - In2.Cu
      - F.SilkS
      - B.SilkS
      - F.Mask
      - B.Mask
      - F.Paste
      - B.Paste
      - Edge.Cuts

  - name: JLCPCB_drill
    comment: Drill files compatible with JLCPCB
    type: excellon
    dir: JLCPCB
    options:
      pth_and_npth_single_file: false
      pth_id: '-PTH'
      npth_id: '-NPTH'
      metric_units: true
      map: gerber
      route_mode_for_oval_holes: false
      output: "%f%i.%x"

  - name: JLCPCB_position
    comment: Pick and place file, JLCPCB style
    type: position
    dir: JLCPCB
    options:
      variant: rotated
      output: '%f_cpl_jlc.%x'
      format: CSV
      units: millimeters
      separate_files_for_front_and_back: false
      only_smd: true
      columns:
        - id: Ref
          name: Designator
        - Val
        - Package
        - id: PosX
          name: "Mid X"
        - id: PosY
          name: "Mid Y"
        - id: Rot
          name: Rotation
        - id: Side
          name: Layer

  - name: JLCPCB_bom
    comment: BoM for JLCPCB
    type: bom
    dir: JLCPCB
    options:
      output: '%f_bom_jlc.%x'
      exclude_filter: 'only_jlc_parts'
      ref_separator: ','
      columns:
        - field: Value
          name: Comment
        - field: References
          name: Designator
        - Footprint
        - field: 'LCSC'
          name: 'LCSC Part #'
      csv:
        hide_pcb_info: true
        hide_stats_info: true
        quote_all: true

  - name: JLCPCB
    comment: ZIP file for JLCPCB
    type: compress
    dir: JLCPCB
    options:
      files:
        - from_output: JLCPCB_gerbers
          dest: /
        - from_output: JLCPCB_drill
          dest: /
        - from_output: JLCPCB_position
          dest: /
        - from_output: JLCPCB_bom
          dest: /
```

## Key Config Notes

- **LCSC field name**: This project uses `LCSC` (not `LCSC#` which is the KiBot sample default)
- **Rotation filter**: `_rot_footprint_jlcpcb` is a KiBot built-in that adjusts component rotations to match JLCPCB's coordinate system
- **BOM filter**: `exclude_filter: 'only_jlc_parts'` confusingly acts as an include filter — it includes only parts with valid LCSC codes
- **Existing panel outputs**: `panel/jlcpcb_1x1/gerbers/` has manually-generated JLCPCB files (bom.csv, pos.csv) for reference

## Checklist

1. [ ] Fix `5V108` and `3V108` reference designators in KiCad (rename to NT110/NT111 or similar)
2. [ ] Place `.kibot.yaml` at repo root (copy from this file)
3. [ ] Run Docker command above
4. [ ] Verify JLCPCB/ output: gerbers, drill, BOM CSV, CPL CSV, ZIP
5. [ ] Optionally fix cosmetic warnings (trailing spaces, malformed values)
6. [ ] Commit JLCPCB/ output files to repo

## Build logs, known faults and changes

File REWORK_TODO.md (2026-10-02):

# ⚠️ REWORK REQUIRED — SD_IN / SD_OUT data lines swapped

**Date found:** 2026-06-18
**Status:** Confirmed on bench. Needs a board respin.

## The bug
On the TDM expansion-header interface between this daughtercard
(`t-dsp_tac5212_pro_audio_module`) and the host `teensy41_digital_audio_board`,
the audio **data lines SD_IN and SD_OUT (codec DIN / DOUT) are swapped.**

The Teensy's TX data (SAI1 OUT1A) lands on the codec's **DOUT** pin (an output)
instead of **DIN**, so the DAC starves → **silent output**. Clocks are fine, so
the codec's PLL still locks and everything *looks* healthy over I²C — which is
what made this sneaky.

## Proof
Bridging the header's SD_IN + SD_OUT pins together makes audio play (TX data now
also reaches DIN). Capture stays dead under the bodge because the codec's DOUT
driver contends with the Teensy TX on the shared node.

## Root cause
- Host header uses **odd/even** pin numbering: `DSP_DATA_IN = 7`, `DSP_DATA_OUT = 9`.
- This module's J1 uses **sequential** numbering: `DOUT = 4`, `DIN = 5`.
- Mixed numbering conventions across the mating connector crossed the pair.

## The fix
- **The host board is believed CORRECT.** Its header follows the **FreeDSP
  expansion-header standard.** → **TODO: confirm against the FreeDSP pinout spec
  before respinning.**
- **Respin THIS module** to swap its SD_IN / SD_OUT header pins so DIN/DOUT match
  the FreeDSP / host pinout.
- Not fixable in Teensy firmware: SAI1 pads are fixed (pin 7 = TX_DATA, pin 8 =
  RX_DATA) and can't swap roles. (Possible-but-unverified stopgap: a TAC5212
  pin-mux / INTF_CFG ASI reroute to receive DAC data on the DOUT pin.)

---

# Output filter: 10 R / 4.7 nF -> 220 R / 10 nF C0G (harsh top end)

**Date:** 2026-10-02
**Status:** Decided. BOM change only, no layout change. Bench-confirm first with a test cap at the jack.

R108 / R111 / R132 / R135 10 R -> 220 R (C22962); C113 / C114 / C120 / C122 4.7 nF -> 10 nF C0G
50 V (C85973). Corner moves from 3.4 MHz to 72 kHz so the DAC's out-of-band noise no longer
reaches the amplifier. Full write-up: `documentation/output-filter-change.md`.

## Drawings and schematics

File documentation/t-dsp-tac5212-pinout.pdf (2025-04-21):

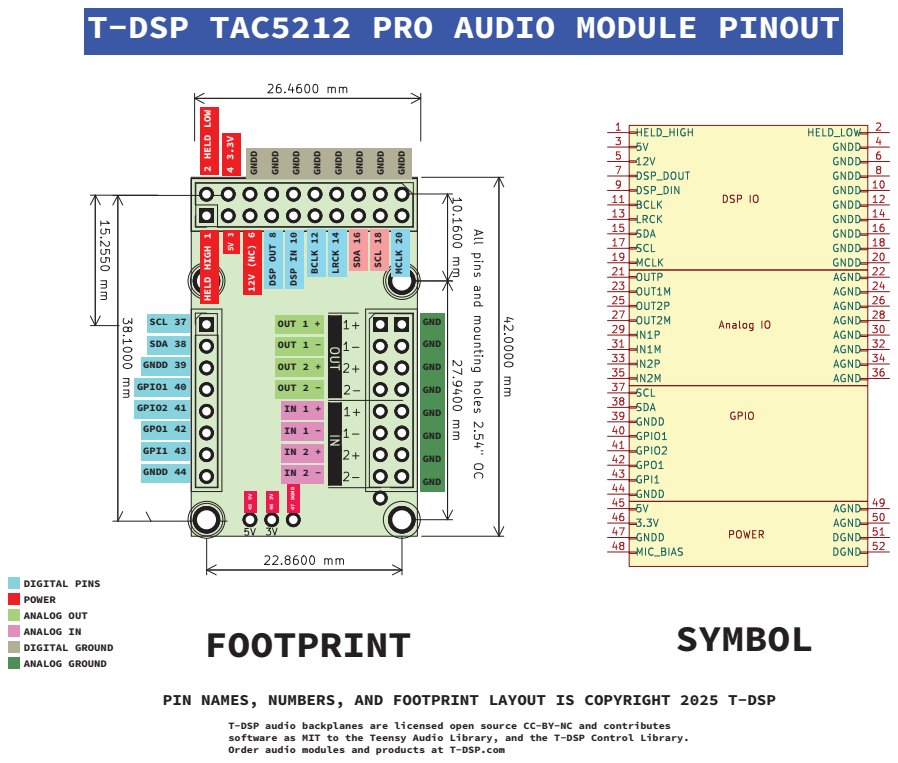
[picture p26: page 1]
T-DSP TAC5212 PRO AUDIO MODULE PINOUT 2 HELD LOW; 12V (NC) 6 DSP OUT 8 DSP IN 10 BCLK 12 LRCK 14 SDA 16 SCL 18 MCLK 20 HELD HIGH 1; GNDD GNDD GNDD GNDD GNDD GNDD GNDD GNDD; SCL 37 SDA 38 GNDD 39 GPIO1 40 GPIO2 41 GPO1 42 GPI1 43 GNDD 44; OUT 1 + OUT 1 - OUT 2 + OUT 2 - IN 1 + IN 1 - IN 2 + IN 2 -; GND; 47 DGND; DIGITAL PINS POWER ANALOG OUT ANALOG IN DIGITAL GROUND ANALOG GROUND; FOOTPRINT; SYMBOL

PIN NAMES, NUMBERS, AND FOOTPRINT LAYOUT IS COPYRIGHT 2025 T-DSP

T-DSP audio backplanes are licensed open source CC-BY-NC and contributes
software as MIT to the Teensy Audio Library, and the T-DSP Control Library.
Order audio modules and products at T-DSP.com

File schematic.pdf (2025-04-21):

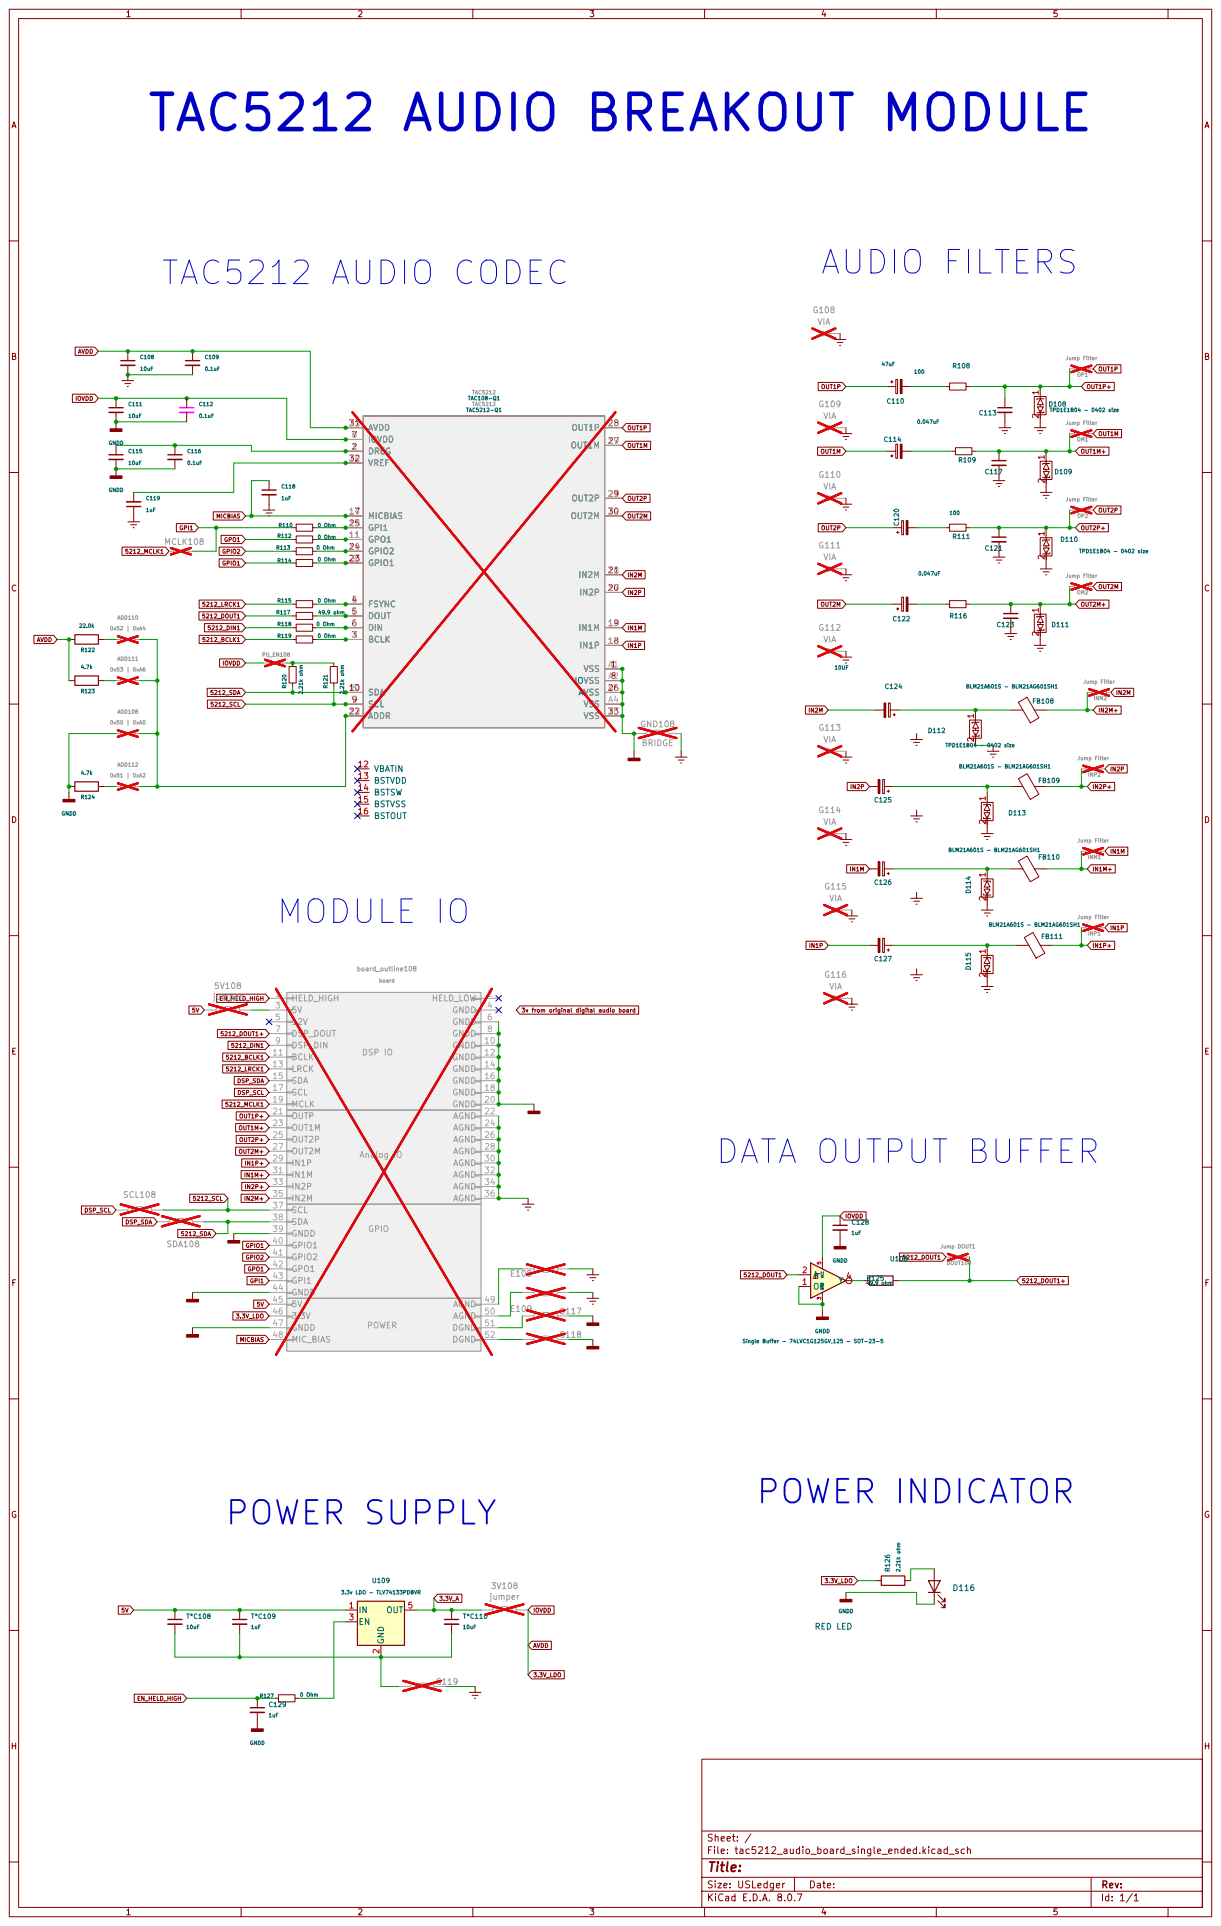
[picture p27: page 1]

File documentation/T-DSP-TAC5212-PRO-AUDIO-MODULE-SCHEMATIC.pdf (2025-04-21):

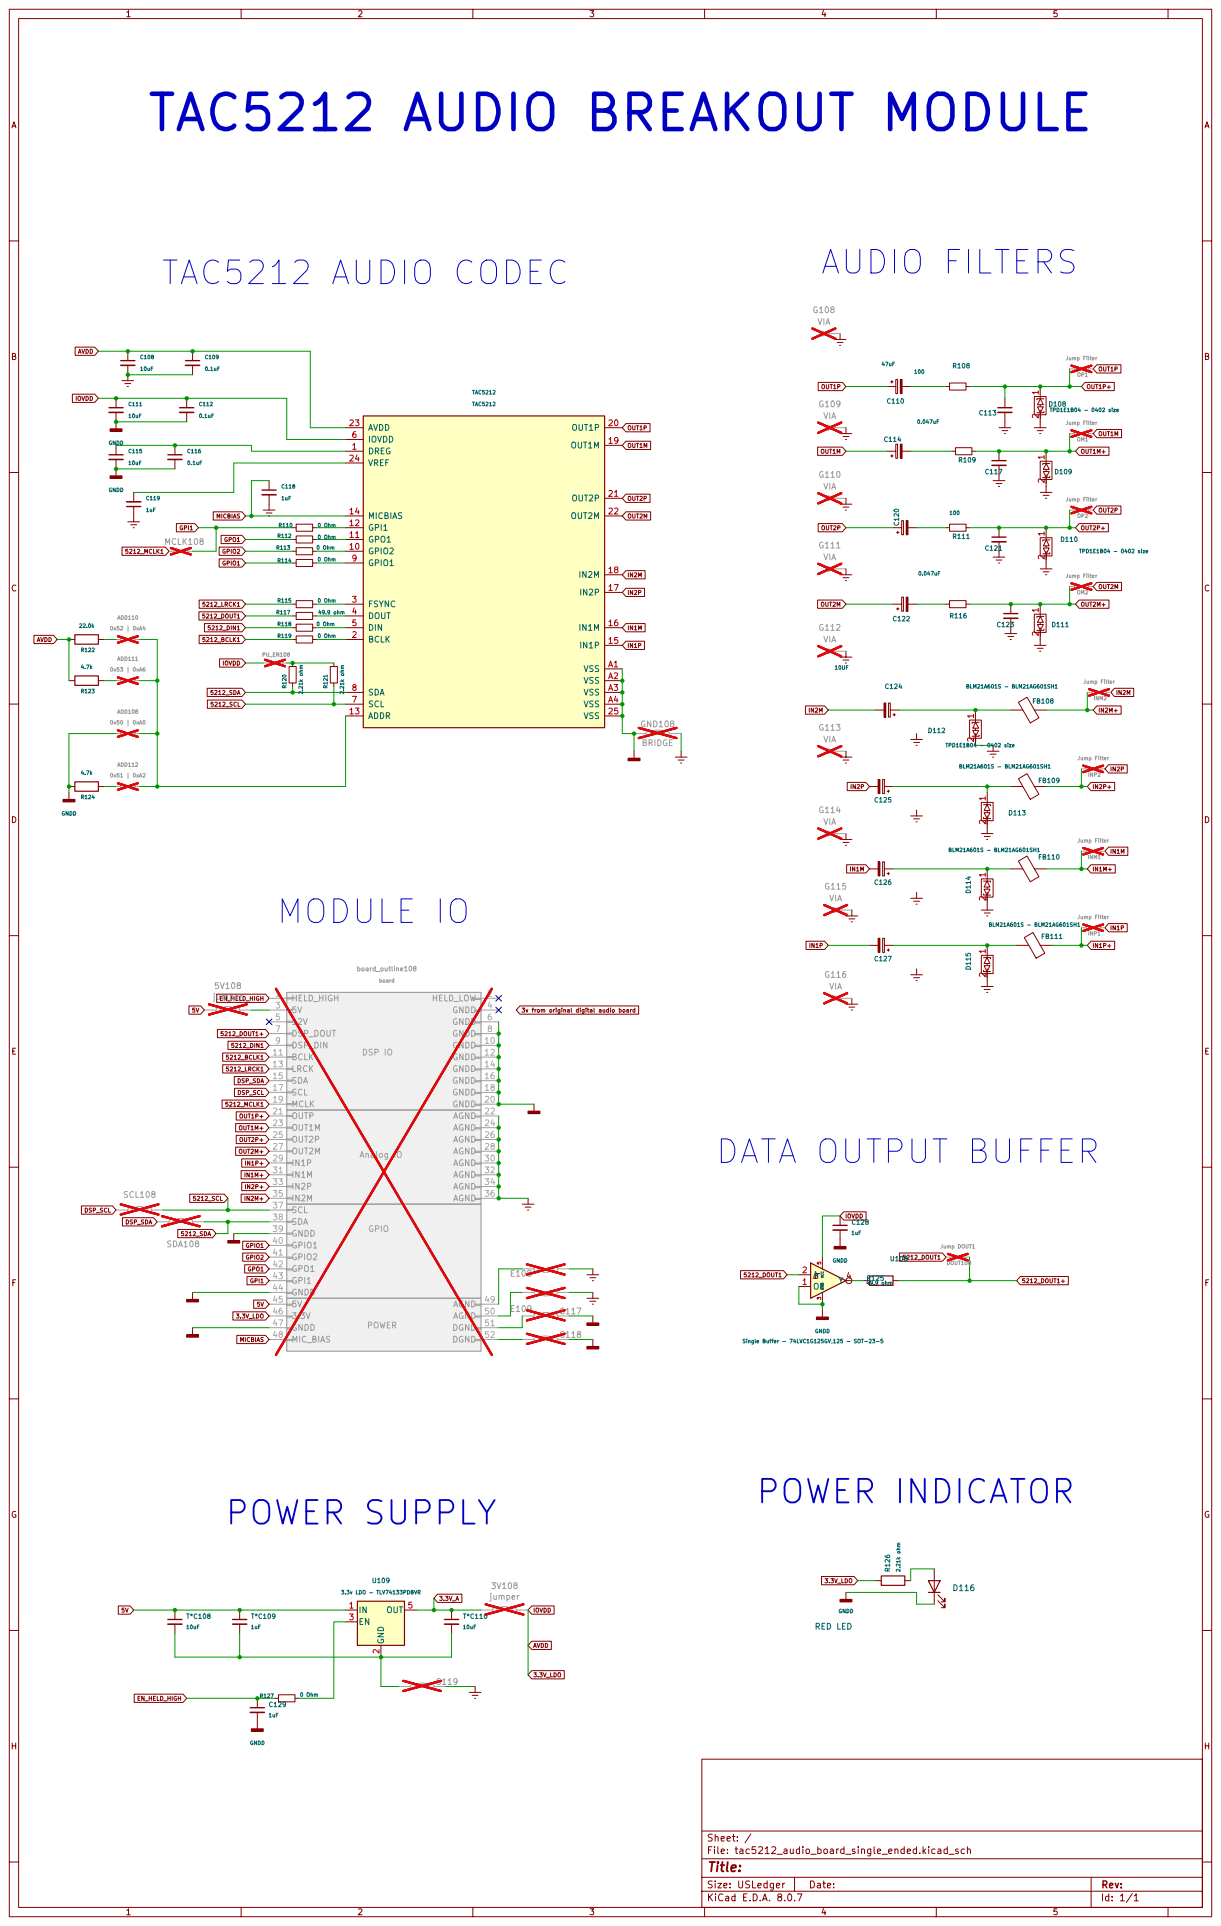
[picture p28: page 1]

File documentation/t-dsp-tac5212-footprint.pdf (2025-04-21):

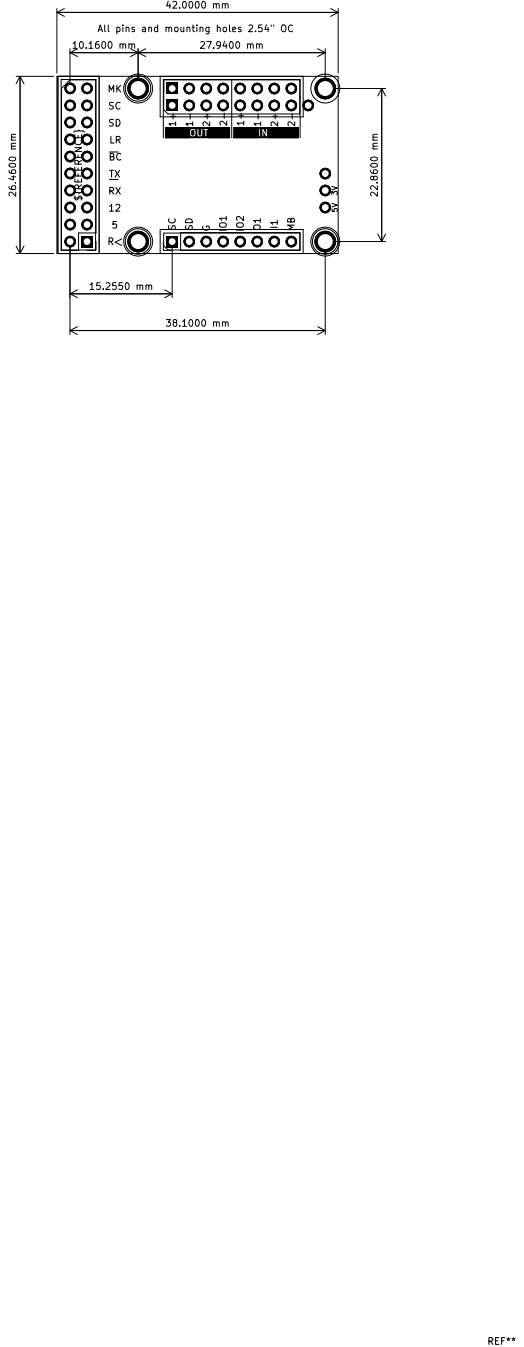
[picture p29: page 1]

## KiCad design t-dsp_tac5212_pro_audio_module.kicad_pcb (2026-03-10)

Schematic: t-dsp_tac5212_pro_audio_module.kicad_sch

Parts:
ADD108: 0x50 | 0xA0; SolderJumper-2_Open_Pad0.5x1.0mm_ADDR; not fitted
ADD110: 0x52 | 0xA4; SolderJumper-2_Open_Pad0.5x1.0mm_ADDR; not fitted
ADD111: 0x53 | 0xA6; SolderJumper-2_Open_Pad0.5x1.0mm_ADDR; not fitted
ADD112: 0x51 | 0xA2; SolderJumper-2_Open_Pad0.5x1.0mm_ADDR; not fitted
C108, C111, C115, C131: 10uF; C_0805_2012Metric_Pad1.18x1.45mm_HandSolder; LCSC C2182156
C109, C112, C116, C128, C129: 0.1uF; C_0402_1005Metric; LCSC C106994
C110, C117, C121, C123: 47uF; CP_EIA-3528-21_Kemet-B_Pad1.50x2.35mm_HandSolder; LCSC C284844; not fitted
C113, C114, C120, C122: 0.0047µF (4.7nF); C_0603_1608Metric_Pad1.08x0.95mm_HandSolder; LCSC C1870901
C118, C119: 1uF; C_0603_1608Metric_Pad1.08x0.95mm_HandSolder; LCSC C2172920
C124, C125, C126, C127: 10uF; C_0603_1608Metric_Pad1.08x0.95mm_HandSolder; LCSC C2167896
C130: 47uF; C_0805_2012Metric_Pad1.15x1.40mm_HandSolder; LCSC C16780
D108, D109, D110, D111, D112, D113, D114, D115: TPD1E10B06DPYR; D_0402_1005Metric_Pad0.77x0.64mm_HandSolder; LCSC C48260
D116: RED LED; D_0805_2012Metric_custom; LCSC C94868
DOUT108: Jump DOUT1; jumper_slice_disconnected_alt-text; not fitted
E108, E109: jumper; jumper_slice; not fitted
FB108, FB109, FB110, FB111: BLM21A601S - BLM21AG601SH1; L_0805_2012Metric_Pad1.18x1.45mm_HandSolder; LCSC C437406
G108, G109, G110, G111, G112: VIA; SMD_ROUTING_PAD; not fitted
G113, G114, G115, G116, G120, G121, G122, G124: VIA; via; not fitted
G117, G118, G119: jumper; jumper_slice; not fitted
G123: SMD ROUTING PAD; SMD_ROUTING_PAD; not fitted
GND108: BRIDGE; jumper_slice; not fitted
INM1, INM2: VIA; via; not fitted
INP1, INP2: VIA; via; not fitted
J3V108, J5V108: jumper; jumper_slice_1mm; not fitted
MCLK108: jumper; SolderJumper-2_P1.3mm_Open_Pad1.0x1.5mm_Master_Clock; not fitted
NT108, NT109: NetTie_2; NetTie-2_SMD_Pad0.2mm; not fitted
OUTM1, OUTM2: VIA; via; not fitted
OUTP1, OUTP2: VIA; via; not fitted
PU_EN108: JUMPER; SolderJumper-2_Open_Pad0.5x1.0mm_PU; not fitted
R108, R111, R132, R135: 10 ohm; R_0603_1608Metric_Pad1.05x0.95mm_HandSolder; LCSC C22859
R109, R110, R112, R113: 49.9; R_0402_1005Metric_Pad0.72x0.64mm_HandSolder; LCSC C87044
R115, R118, R119: 0 Ohm; R_0402_1005Metric_Pad0.72x0.64mm_HandSolder; LCSC C106231
R117, R125: 33 ohm; R_0402_1005Metric_Pad0.72x0.64mm_HandSolder; LCSC C25105
R120, R121, R140: 2.21k ohm; R_0402_1005Metric; LCSC C138019
R122: 22.0k; R_0402_1005Metric; LCSC C2909337
R123, R124: 4.7k; R_0402_1005Metric; LCSC C105871
R127, R128, R129, R130: DNP; R_0603_1608Metric_Pad1.05x0.95mm_HandSolder; LCSC DNP; not fitted
R134, R161, R162, R163: 0 ohm; R_0603_1608Metric_Pad1.05x0.95mm_HandSolder; LCSC C21189
R136, R137, R138, R139: 100K; R_0603_1608Metric_Pad1.05x0.95mm_HandSolder; LCSC C25803
R199: 2.21k ohm; R_0805_2012Metric_Pad1.20x1.40mm_HandSolder; LCSC C138019; not fitted
SCL108: jumper; jumper_slice; not fitted
SCL109: jumper; jumper_slice_1mm; not fitted
SDA108: jumper; jumper_slice; not fitted
T108, T109, T110, T111: Tab; not fitted
T*C108, T*C110: 10uF; C_0805_2012Metric_Pad1.18x1.45mm_HandSolder; LCSC C2182156
T*C109: 1uF; C_0603_1608Metric_Pad1.08x0.95mm_HandSolder; LCSC C2172920
TAC108-Q1: TAC5212-Q1; Texas_RHB0032E_VQFN-32-1EP_5x5mm_P0.5mm_EP3.45x3.45mm_Therm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; not fitted
TAC5212: TAC5212IRGER; VQFN-24-1EP_4x4mm_P0.5mm_EP2.45x2.45mm_ThermalVias; LCSC C44853694
U108: Single Buffer with Tri-state Passthru - SN74LVC1G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; SOT-353_SC-70-5; LCSC C113518
U109: 3.3v LDO - TLV74133PDBVR; SOT-23-5; LCSC C471862
board_outline108: board; audio_module_board_outline_50x34.5_e1; not fitted

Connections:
3.3V_A: J3V108.2, T*C110.1, U109.5 (OUT)
3.3V_LDO: J3V108.1, NT109.1, R122.2, R123.2, R140.1
3.3V_THIN: C108.1, C109.1, NT109.2, TAC108-Q1.31 (AVDD), TAC5212.23 (AVDD)
3.3v_IDE: C111.1, C112.1, C128.1, C131.1, PU_EN108.2, SCL109.2, TAC108-Q1.7 (IOVDD), TAC5212.6 (IOVDD), U108.4 (OE^), U108.5 (VCC), board_outline108.4 (3.3V)
5V: C130.1, J5V108.1, NT108.1
5V_THIN: NT108.2, T*C108.1, T*C109.1, U109.1 (IN)
5212_BCLK1: R119.1, board_outline108.11 (BCLK)
5212_DIN1: R118.1, board_outline108.7 (DSP_DOUT)
5212_DOUT1: DOUT108.1, R117.1, U108.1 (A)
5212_DOUT1+: DOUT108.2, R125.1, board_outline108.9 (DSP_DIN)
5212_LRCK1: R115.1, board_outline108.13 (LRCK)
5212_MCLK1: MCLK108.1, board_outline108.19 (MCLK)
5212_SCL: R121.1, SCL108.2, TAC108-Q1.9 (SCL), TAC5212.7 (SCL), board_outline108.37 (SCL)
5212_SDA: R120.1, SDA108.2, TAC108-Q1.10 (SDA), TAC5212.8 (SDA), board_outline108.38 (SDA)
DSP_SCL: SCL108.1, board_outline108.17 (SCL)
DSP_SDA: SDA108.1, board_outline108.15 (SDA)
EN_HELD_HIGH: C129.1, R199.1, U109.3 (EN), board_outline108.1 (HELD_HIGH)
Earth: C108.2, C109.2, C113.2, C114.2, C118.2, C119.1, C120.2, C122.2, D108.2 (K), D109.2 (K), D110.2 (K), D111.2 (K), D112.2 (K), D113.2 (K), D114.2 (K), D115.2 (K), E108.1, E109.2, G108.1, G109.1, G110.1, G111.1, G112.1, G113.1, G114.1, G115.1, G116.1, G119.2, G120.1, G121.1, G122.1, G123.1, GND108.2, R136.2, R137.2, R138.2, R139.2, board_outline108.22 (AGND), board_outline108.24 (AGND), board_outline108.26 (AGND), board_outline108.28 (AGND), board_outline108.30 (AGND), board_outline108.32 (AGND), board_outline108.34 (AGND), board_outline108.36 (AGND)
GNDD: ADD108.1, C111.2, C112.2, C115.2, C116.2, C128.2, C129.2, C130.2, C131.2, D116.1 (K), G117.2, G118.2, GND108.1, R124.2, TAC108-Q1.1 (VSS), TAC108-Q1.8 (IOVSS), TAC108-Q1.15 (BSTVSS), TAC108-Q1.26 (AVSS), TAC108-Q1.33 (VSS), TAC5212.25 (VSS), TAC5212.A1 (VSS), TAC5212.A2 (VSS), TAC5212.A3 (VSS), TAC5212.A4 (VSS), U108.3 (GND), board_outline108.6 (GNDD), board_outline108.8 (GNDD), board_outline108.10 (GNDD), board_outline108.12 (GNDD), board_outline108.14 (GNDD), board_outline108.16 (GNDD), board_outline108.18 (GNDD), board_outline108.20 (GNDD), board_outline108.39 (GNDD), board_outline108.44 (GNDD)
GPI1: MCLK108.2, TAC108-Q1.25 (GPI1A), TAC5212.12 (GPI1), board_outline108.43 (GPI1)
GPIO1: TAC108-Q1.11 (GPIO1), TAC5212.9 (GPIO1), board_outline108.40 (GPIO1)
GPIO2: TAC108-Q1.24 (GPI2A), TAC5212.10 (GPIO2), board_outline108.41 (GPIO2)
GPO1: TAC108-Q1.23 (GPO1A), TAC5212.11 (GPO1), board_outline108.42 (GPO1)
IN1M: C126.2, INM1.1, TAC108-Q1.19 (IN1M), TAC5212.16 (IN1M)
IN1M+: R112.2, board_outline108.31 (IN1M)
IN1P: C127.2, INP1.1, TAC108-Q1.18 (IN1P), TAC5212.15 (IN1P)
IN1P+: R113.2, board_outline108.29 (IN1P)
IN2M: C124.2, INM2.1, TAC108-Q1.21 (IN2M), TAC5212.18 (IN2M)
IN2M+: R110.2, board_outline108.35 (IN2M)
IN2P: C125.2, INP2.1, TAC108-Q1.20 (IN2P), TAC5212.17 (IN2P)
IN2P+: R109.2, board_outline108.33 (IN2P)
MICBIAS: C118.1, TAC108-Q1.17 (MICBIAS), TAC5212.14 (MICBIAS), board_outline108.48 (MIC_BIAS)
unnamed: ADD110.1, R122.1
unnamed: ADD111.1, R123.1
unnamed: ADD112.1, R124.1
unnamed: C110.1, C113.1, R108.1, R127.1, R161.2
unnamed: C114.1, C117.1, R111.1, R128.1, R162.2
unnamed: C120.1, C121.1, R129.1, R132.1, R163.2
unnamed: C122.1, C123.1, R130.1, R134.2, R135.1
unnamed: C124.1, FB108.2, R136.1
unnamed: C125.1, FB109.2, R137.1
unnamed: C126.1, FB110.2, R138.1
unnamed: C127.1, FB111.2, R139.1
unnamed: D112.1 (K), FB108.1, R110.1
unnamed: D113.1 (K), FB109.1, R109.1
unnamed: D114.1 (K), FB110.1, R112.1
unnamed: D115.1 (K), FB111.1, R113.1
unnamed: D116.2 (A), R140.2
unnamed: E108.2, board_outline108.49 (AGND)
unnamed: E109.1, board_outline108.50 (AGND)
unnamed: G117.1, board_outline108.51 (DGND)
unnamed: G118.1, board_outline108.52 (DGND)
unnamed: PU_EN108.1, R120.2, R121.2
unnamed: R199.2, SCL109.1
unnamed: ADD108.2, ADD110.2, ADD111.2, ADD112.2, TAC108-Q1.22 (ADDRA), TAC5212.13 (ADDR)
unnamed: R119.2, TAC108-Q1.3 (BCLK), TAC5212.2 (BCLK)
unnamed: R118.2, TAC108-Q1.6 (DIN), TAC5212.5 (DIN)
unnamed: R117.2, TAC108-Q1.5 (DOUT), TAC5212.4 (DOUT)
unnamed: C115.1, C116.1, TAC108-Q1.2 (DREG), TAC5212.1 (DREG)
unnamed: R115.2, TAC108-Q1.4 (FSYNC), TAC5212.3 (FSYNC)
unnamed: C119.2, TAC108-Q1.32 (VREF), TAC5212.24 (VREF)
unnamed: R125.2, U108.2 (B)
unnamed: G119.1, T*C108.2, T*C109.2, T*C110.2, U109.2 (GND)
unnamed: J5V108.2, board_outline108.3 (5V)
OUT1M: OUTM1.1, R111.2, R128.2, TAC108-Q1.27 (OUT1M), TAC5212.19 (OUT1M)
OUT1M+: C117.2, D109.1 (K), R162.1, board_outline108.23 (OUT1M)
OUT1P: OUTP1.1, R108.2, R127.2, TAC108-Q1.28 (OUT1P), TAC5212.20 (OUT1P)
OUT1P+: C110.2, D108.1 (K), R161.1, board_outline108.21 (OUTP)
OUT2M: OUTM2.1, R130.2, R135.2, TAC108-Q1.30 (OUT2M), TAC5212.22 (OUT2M)
OUT2M+: C123.2, D111.1 (K), R134.1, board_outline108.27 (OUT2M)
OUT2P: OUTP2.1, R129.2, R132.2, TAC108-Q1.29 (OUT2P), TAC5212.21 (OUT2P)
OUT2P+: C121.2, D110.1 (K), R163.1, board_outline108.25 (OUT2P)

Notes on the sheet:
TAC5212 AUDIO CODEC
POWER SUPPLY
MODULE IO
REPLACE WITH ANALOG BUFFER SUCH AS SN74LVC1G66 SO THERE IS NO CONTENTION BETWEEN THE SUB-MODULES!
DATA OUTPUT BUFFER
AUDIO FILTERS
T-DSP TAC5212 Pro Audio Module
POWER INDICATOR
# TAC5212 Audio Module - Input/Output Interface Documentation ## Document Control | Version | Date | Author | Changes | |---------|------|--------|---------| | 1.0 | [Date] | [Name] | Initial release | --- ## Module Overview The TAC5212 audio module provides flexible, high-quality audio input and o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
PANEL TABS

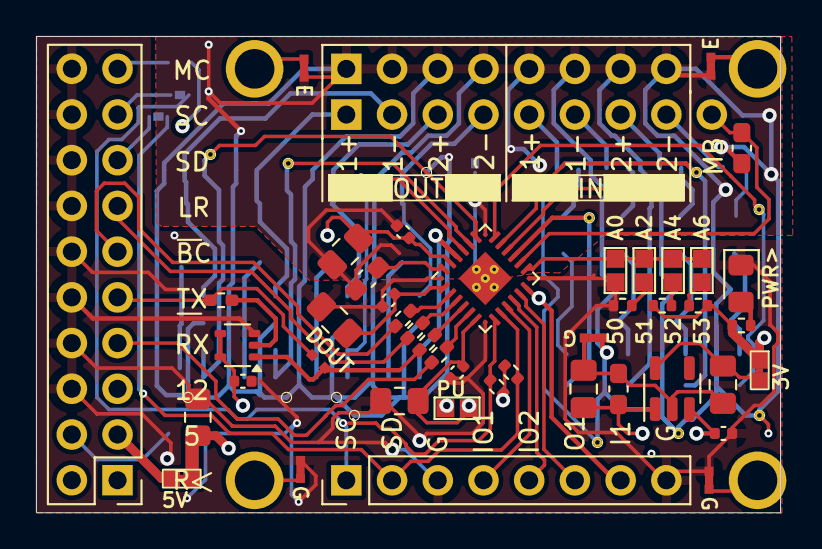
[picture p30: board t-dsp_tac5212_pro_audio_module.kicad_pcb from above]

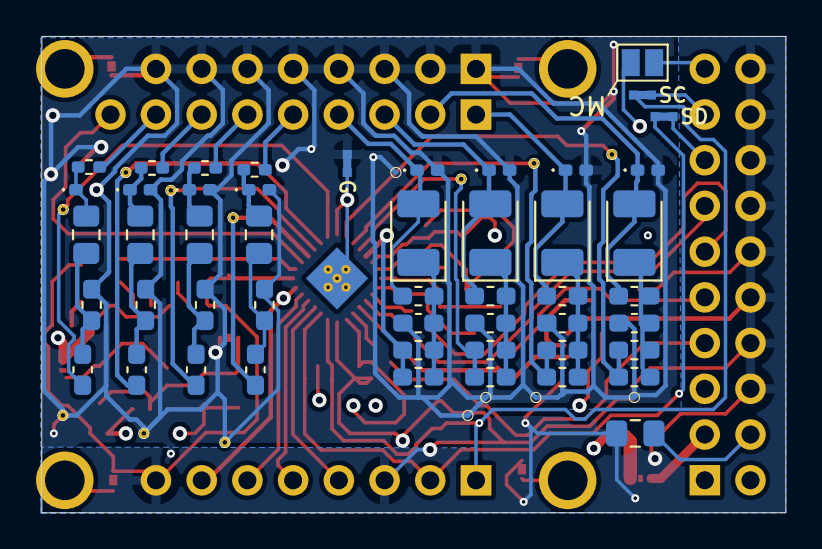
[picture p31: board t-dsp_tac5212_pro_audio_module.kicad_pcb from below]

Board: 4 copper layers, 41.3 x 26.5 mm, 113 parts (64 on the bottom side), 71 nets.

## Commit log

2024-08-25 added enable (held-high)
    [tac5212_audio_board_single_ended.kicad_pcb, tac5212_audio_board_single_ended.kicad_sch, tac5212_audio_board_single_ended.step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]
2025-04-21 finish wqfn
    [tac5212_audio_board_single_ended.kicad_pcb]
2025-08-20 working on production
    [jlc_pcba-CmtUser.gbr, jlc_pcba-CuBottom.gbl, jlc_pcba-CuTop.gtl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]
2025-08-21 update fab
    [jlcpcb_1x1-CmtUser.gbr, jlcpcb_1x1-CuBottom.gbl, jlcpcb_1x1-CuTop.gtl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]
2026-02-07 Prepare repo for public release under CC BY-NC-SA 4.0 - Add LICENSE file (CC BY-NC-SA 4.0) and README with T-DSP project description, audio specs, modular architecture, and pinout diagram - Remove th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
    [2.54 mm DUPONT MALE PIN HEADER, IO, 2X20, RPi4ModelB.SLDPRT, 2.54 mm DUPONT MALE PIN HEADER, IO, 2X40, RPi4ModelB.SLDPRT, 2.54 mm DUPONT MALE PIN HEADER, POE, 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]
2026-02-07 Rename project to T-DSP TAC5212 Pro Audio Module
    - Rename all KiCad project files from tac5212_audio_board_single_ended
    to t-dsp_tac5212_pro_audio_module
    - Update internal filename references in .kicad_pro and .kicad_prl
    - Rename schematic/footprint PDFs and move to documentation/
    - Update README: new title, corrected connector/module descriptions,
    add 3D renders, pinout diagram, interactive BOM link, and docs links
    - Update kikit_script.txt with new project filenames
    - Clean up .gitignore (remove redundant lock file entry)
    - Add LICENSE (CC BY-NC-SA 4.0)
    [t-dsp_tac5212_pro_audio_module.kicad_pcb, t-dsp_tac5212_pro_audio_module.kicad_sch, t-dsp_tac5212_pro_audio_module.step]
2026-02-07 Add hardware photos to README
    - Bare module photo (top and bottom) as hero image
    - Real backplane prototype photo
    - Rack-mounted bench prototype photo
2026-02-07 Rename documentation files to lowercase and add footprint image
2026-02-07 Add context for earlier bench prototype photo
2026-02-07 Add Teensy and Teensy Audio Library references with links
2026-02-08 Fix README audio specs against TAC5212 datasheet
    Correct gain claim (12dB analog, not 60dB), input impedance
    (programmable 5k/10k/40k, not 100k), headphone power (62.5mW@16ohm,
    ~31mW@32ohm), output swing (2 VRMS differential), and label I/O as
    differential pairs.
2026-02-08 Correct README audio input specs
    Fix input voltage range to 2 VRMS differential, clarify instrument
    input requires external preamp/buffer, note preamp modules on roadmap.
2026-02-08 Add KiCanvas links for online schematic and PCB viewing
2026-02-08 Add interactive 3D model (STL) export of PCB
    Exported via kicad-cli. GitHub renders STL files interactively in the
    browser.
    [t-dsp_tac5212_pro_audio_module.stl]
2026-02-09 fix all drc errors.
    [t-dsp_tac5212_pro_audio_module.kicad_pcb, t-dsp_tac5212_pro_audio_module.kicad_sch]
2026-02-09 Add KiBot CI/CD pipeline for JLCPCB manufacturing files
    - Add .kibot.yaml config for gerbers, drill, BOM, CPL, and ZIP output
    - Add GitHub Actions workflow triggered on push to main and manual dispatch
    - Add release job to attach JLCPCB ZIP to GitHub Releases on version tags
    - Fix malformed reference designators (5V108, 3V108) that blocked KiBot BOM/CPL
    - Add local build instructions to README
    [t-dsp_tac5212_pro_audio_module.kicad_pcb, t-dsp_tac5212_pro_audio_module.kicad_sch]
2026-02-09 Fix workflow to trigger on version tags
    Add tags filter so tag pushes (e.g. v0.92) trigger the release job.
2026-02-09 Add LCSC part number for U108 (SN74LVC1G66DCK)
    Add C113518 to complete JLCPCB BOM coverage for all active components.
    [t-dsp_tac5212_pro_audio_module.kicad_sch]
2026-02-09 Add generic BOM output for PCBWay and other fab houses
    Includes Manufacturer, MPN, Package, LCSC, Digikey, Mouser, and Description
    columns. Also uploaded as a separate artifact and attached to releases.
2026-02-09 Add LCSC enrichment, iBOM, and consolidate manufacturing pipeline
    - Enrich schematic with LCSC_Manufacturer and LCSC_MPN for all components
    - Add enrichment and verification scripts (scripts/)
    - Consolidate all outputs into single project-named folder
    - Both BOMs (JLCPCB + generic with MPN) included in manufacturing ZIP
    - Add interactive BOM generation and GitHub Pages deployment
    - Remove deprecated gerber/, bom/, and panel/ folders (replaced by CI)
    [COST CALc.xlsx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]
2026-02-09 Fix Package field conflicts and enable gerber job file
    - C128: Package C0603 → C0402 (matches footprint)
    - C124: Package C0805 → C0603 (matches footprint)
    - Enable gerber job file for automatic layer identification by fabs
    [t-dsp_tac5212_pro_audio_module.kicad_sch]
2026-02-09 Add schematic and PCB layout PDFs to manufacturing output
    [t-dsp_tac5212_pro_audio_module.kicad_sch]
2026-02-09 Fix BOM field conflicts and component data errors
    - Fix R126 LCSC code (C60491 100K -> C138019 2.21K) in schematic and PCB
    - Fix Package/Case mismatches in PCB: C128 (C0603->C0402), C124 (C0805->C0603)
    - Fix Description fields: remove MISMATCH FOOTPRINT notes, correct 0603->0402
    for R122, R123, R124; unify R125 description to match R117
    - Fix D116 LED Package/Case from 1206(CHECKME) to 0805
    - Add schematic PDF and PCB layout PDF to manufacturing ZIP
    [t-dsp_tac5212_pro_audio_module.kicad_pcb, t-dsp_tac5212_pro_audio_module.kicad_sch]
2026-02-09 Add version, date, and license to manufacturing outputs
    - Add KiBot preflight to auto-populate REVISION (git tag) and DATE variables
    - Replace static "V0.91" silkscreen text with ${REVISION} variable
    - Add schematic title block with date, revision, copyright, and CC BY-NC-SA license
    - Remove reference designator printing from gerber silkscreen and PCB PDF
    - Hide footprint refs on F.Cu, F.SilkS, B.Cu, B.SilkS in PCB PDF output
    [t-dsp_tac5212_pro_audio_module.kicad_pcb, t-dsp_tac5212_pro_audio_module.kicad_sch]
2026-02-09 Enable update_pcb_text_cache for silkscreen text variable resolution
    KiCad 9 does not re-resolve ${REVISION} on silkscreen after cache
    invalidation. Use update_pcb_text_cache to write resolved values
    directly into the PCB's text variable cache.
2026-02-09 Add version to ZIP filename and PCB title block
    - Add PCB title_block with ${REVISION} so %r resolves in output filenames
    - ZIP now named t-dsp_tac5212_pro_audio_module-manufacturing_v0.98.zip etc.
    [t-dsp_tac5212_pro_audio_module.kicad_pcb]
2026-02-10 Add auto-generated PCB spec to manufacturing ZIP
    Adds a KiBot report output that generates board specifications
    (dimensions, layer stackup, materials, track/drill specs) from
    PCB metadata. Included in the manufacturing ZIP for manufacturer
    reference.
2026-02-10 Add 3D renders, hide ref designators, fix legacy 3D model paths
    - Add Blender 3D render output (8 views: top, bottom, 4 sides, 2 isometric)
    to KiBot config and manufacturing ZIP
    - Split CI workflow into 3 steps: manufacturing outputs, 3D renders
    (kicad9_auto_full), and ZIP packaging
    - Add PCB spec report to manufacturing outputs
    - Hide reference designators and component values from silkscreen
    - Replace legacy ${KISYS3DMOD} with ${KICAD9_3DMODEL_DIR} across all
    footprint libraries and PCB (47 files)
    - Add new 3D models (TPD1E10B06, VQFN-24) and footprints
    - Set net tie footprint type on jumper components
    [TPD1E10B06DPYR.STEP, VQFN-24-1EP_4x4mm_P0.5mm_EP2.45x2.45mm.step, t-dsp_tac5212_pro_audio_module.kicad_pcb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]
2026-02-24 Add 3D render gallery, update schematic for production
    - Add interactive 3D render gallery with All Components / SMD Only tabs
    - Add gallery.html page deployed to GitHub Pages alongside iBOM
    - Update KiBot config: _th_ prefix file_ids, exclude_tht filter, 3d_renders_smd output
    - Update CI workflow to deploy renders and gallery to GitHub Pages
    - Update README with gallery thumbnail grid and links
    - Schematic updates: 49.9Ω ADC input resistors, 100K bias pull-downs, component refinements
    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
    [t-dsp_tac5212_pro_audio_module.kicad_pcb, t-dsp_tac5212_pro_audio_module.kicad_sch, t-dsp_tac5212_pro_audio_module.step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]
2026-03-10 Shrink board size to match Teensy audio adaptor shield dimensions
    Update board outline width (42mm → 41.34mm), add connector 3D models
    for pin sockets, and refresh PCB layout.
    [t-dsp_tac5212_pro_audio_module.kicad_pcb, t-dsp_tac5212_pro_audio_module_pcb_mount.step]
2026-10-02 Document the DAC output filter change (220 R / 10 nF C0G) and the bench test
2026-10-05 User WIP (May 2): LT3042 LDO option U110 with R114/R116/J3V109/NT110/C132 and T* option caps
    Committed as found in the working tree, unfinished: 11 unconnected and new clearance
    errors on the board. Committed so the module-part conversion can build on it.
2026-10-05 Backplane part: T-DSP_TAC5212 symbol (4 units) + T-DSP_TAC5212_Socket footprint
    Same method as the core and the other modules, backplane side only: the module keeps its own
    footprint (board_outline108, pads 1-52). Socket pads are the module's pads renumbered J1-n / J2-n /
    J3-n / H1-H4, snapped to one 2.54 mm grid (<= 0.01 mm). Generated by scripts/build_tac5212_lib.py.
2026-10-05 3D model: module board exported to STEP next to the footprints, attached to the Socket footprint
    The generator exports the module board (origin = module top-left, --step re-exports) and gives the
    Socket footprint the model 11 mm up (8.5 mm socket + 2.5 mm header spacer). The Module footprint gets
    none (it would draw the board twice). symbol_pins.json is only rewritten with --pins now.
2026-10-09 Output filter: 220 R / 10 nF cancelled (breaks headphone drive); one filter for headphones and line = 10 R / 220 nF C0G 1206, bench test first

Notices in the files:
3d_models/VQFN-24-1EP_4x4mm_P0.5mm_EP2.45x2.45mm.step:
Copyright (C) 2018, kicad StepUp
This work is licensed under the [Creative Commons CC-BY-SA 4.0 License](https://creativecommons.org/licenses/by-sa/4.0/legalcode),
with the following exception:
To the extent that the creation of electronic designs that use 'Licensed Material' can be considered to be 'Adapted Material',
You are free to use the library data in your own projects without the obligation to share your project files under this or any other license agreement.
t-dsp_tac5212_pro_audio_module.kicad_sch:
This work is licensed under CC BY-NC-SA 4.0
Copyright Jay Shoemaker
